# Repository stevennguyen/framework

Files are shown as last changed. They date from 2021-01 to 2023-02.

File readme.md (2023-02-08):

# 7c8 Framework
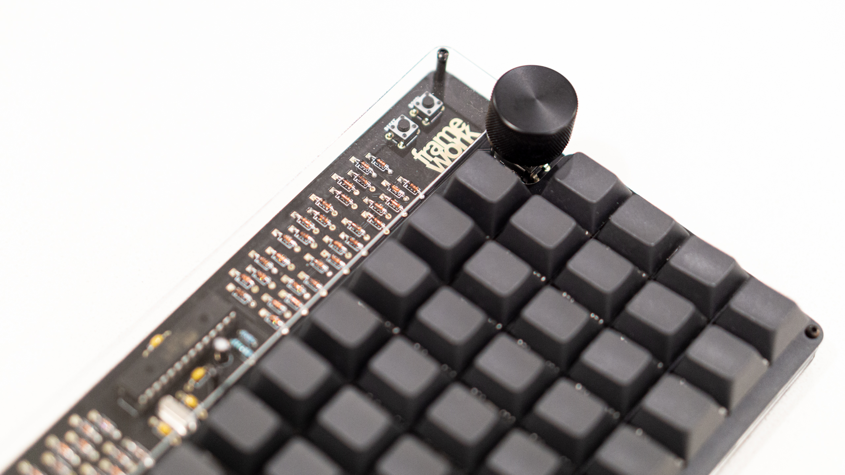
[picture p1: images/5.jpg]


Framework is a 5x12 ortholinear keyboard featuring:

* All through-hole components (except Kailh hotswap sockets)
* QMK firmware with VIA support
* Rotary encoder
* Hotswappable switches
* FR-4 and acrylic sandwich construction
* USB Type-C
* MIT (one 2u), grid (two 1u), and two 2u, bottom row configuration

## Info

### Discord

https://discord.gg/MpxnD9PygN

### License

Framework is licensed under [CC BY-NC-SA 4.0](https://creativecommons.org/licenses/by-nc-sa/4.0/). Please modify my design to make a keyboard that fits you!

### Revisions

**rev0** is an early prototype/proof of concept  
**rev1** is the current revision and should be used for fabrication or modification

### General

The ATmega328P does not come with a USB bootloader from factory. You will need to flash the chip with a bootloader through the ISP header first. You can find a pre-compiled .hex to flash at [USBaspLoader/bootloader.hex](USBaspLoader/bootloader.hex), or compile your own using the documentation found in the [USBaspLoader/](USBaspLoader/) folder. Everything has been preconfigured for use with the Framework.

[USBaspLoader](https://github.com/baerwolf/USBaspLoader) is a project maintained by [Stephan Baerwolf](https://github.com/baerwolf).

Fuse bytes should be:
* lfuse = 0xd7
* hfuse = 0xd0
* efuse = 0x04

After [setting up your QMK environment](https://docs.qmk.fm/#/newbs_getting_started), flash the Framework firmware:

```
make 7c8/framework:default:flash # default keymap
make 7c8/framework:via:flash     # via-compatible keymap
```

Alternatively, a precompiled .hex with bootloader and Framework QMK firmware with VIA support can be found at [firmware/bl_framework_via.hex](firmware/bl_framework_via.hex). Flashing/fusing with avrdude looks like this:

```
avrdude -c <programmer> -p atmega328p -U flash:w:bl_framework_via.hex:i -U lfuse:w:0xd7:m -U hfuse:w:0xd0:m -U efuse:w:0x04:m
```

### Layout

Framework supports MIT, grid, and 2x2u spacebar layouts. Refer to [framework.h](https://github.com/qmk/qmk_firmware/blob/master/keyboards/7c8/framework/framework.h). Layout options are also configurable in VIA.

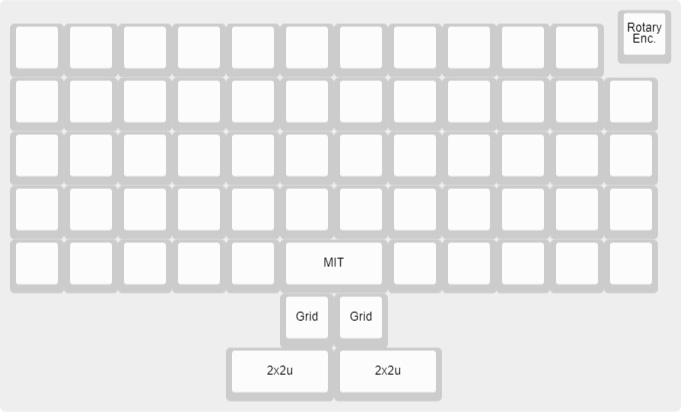
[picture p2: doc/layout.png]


### Physical construction

Please see [this separate note on physical construction](doc/physical_construction.md).

### Build guide

Please see the [build guide](doc/build_guide) for more information.

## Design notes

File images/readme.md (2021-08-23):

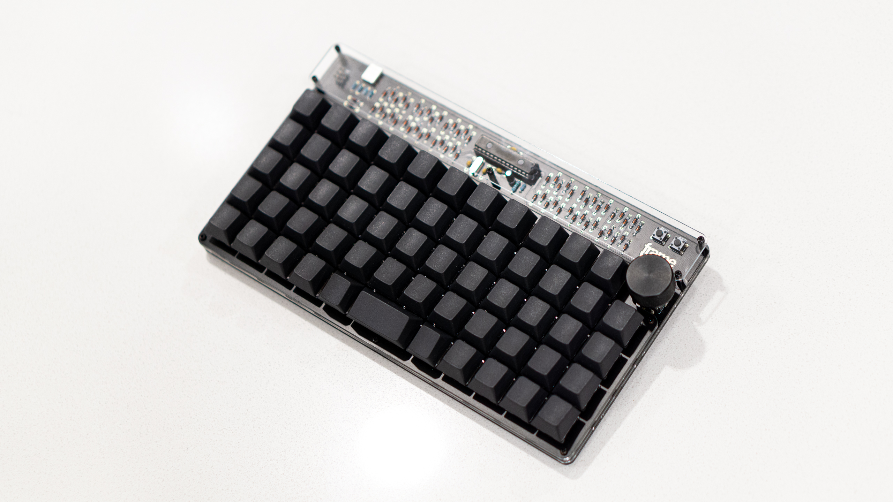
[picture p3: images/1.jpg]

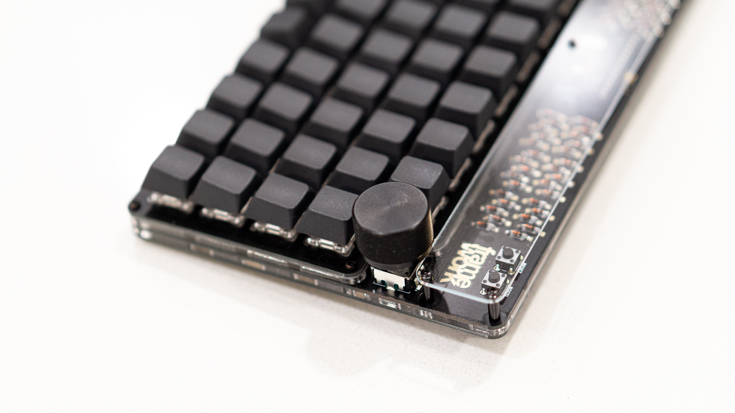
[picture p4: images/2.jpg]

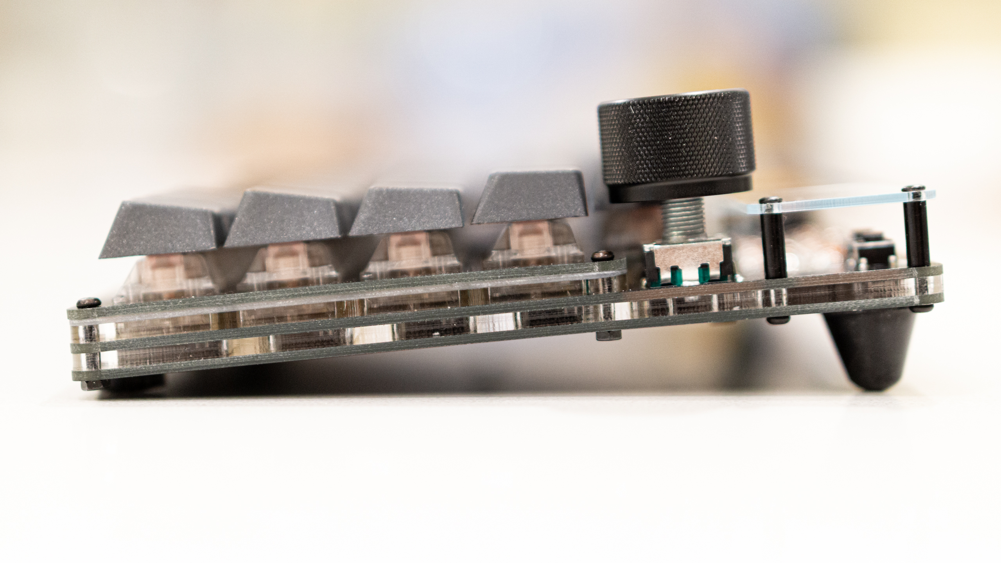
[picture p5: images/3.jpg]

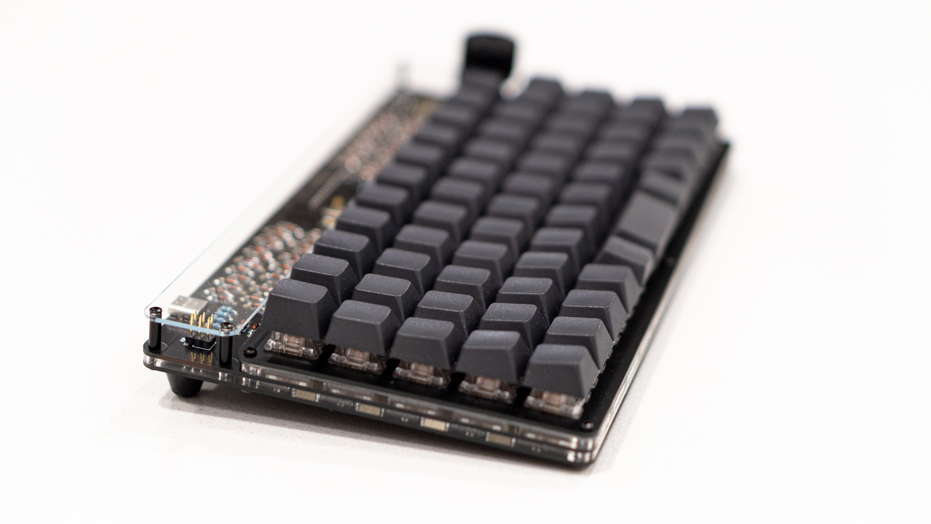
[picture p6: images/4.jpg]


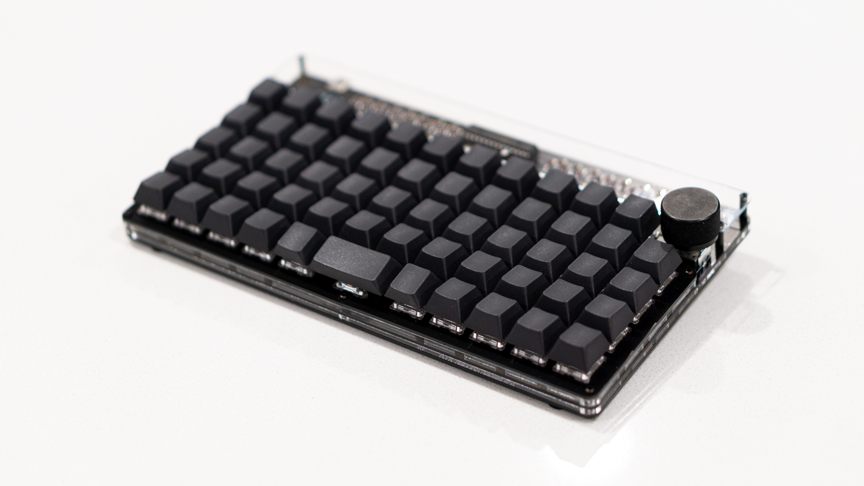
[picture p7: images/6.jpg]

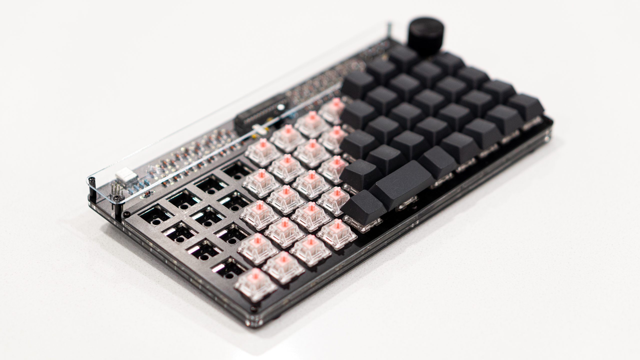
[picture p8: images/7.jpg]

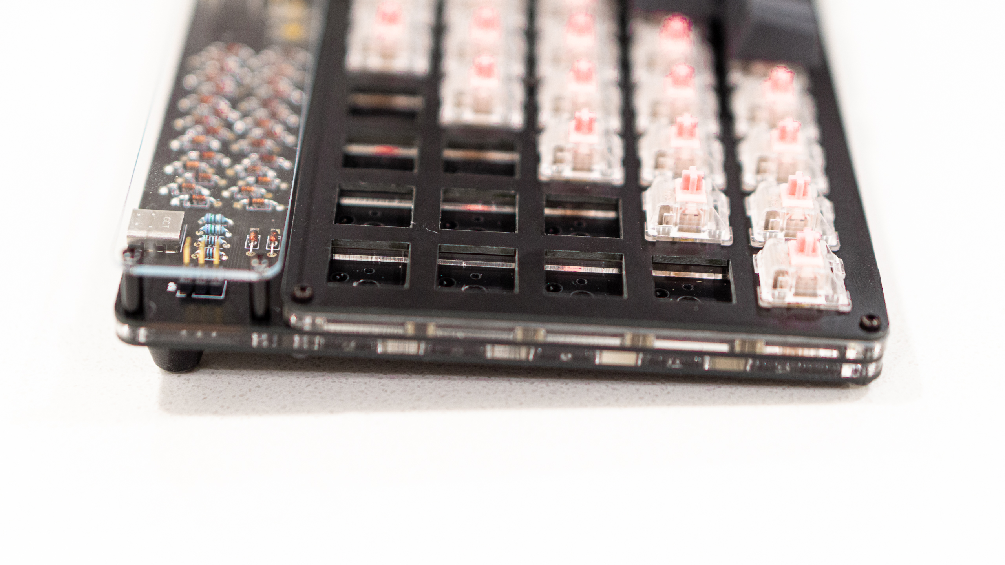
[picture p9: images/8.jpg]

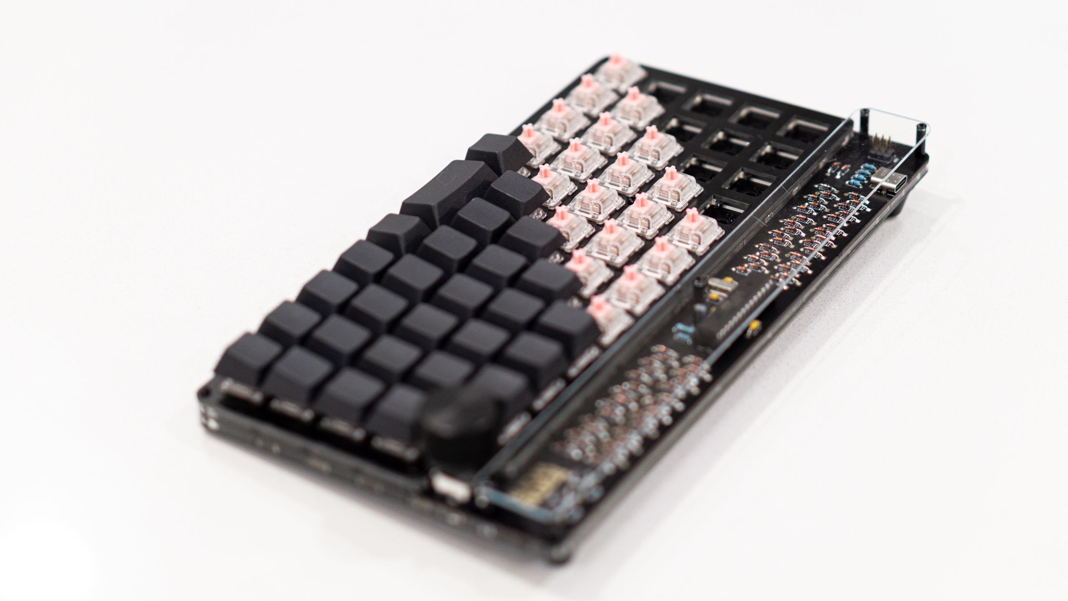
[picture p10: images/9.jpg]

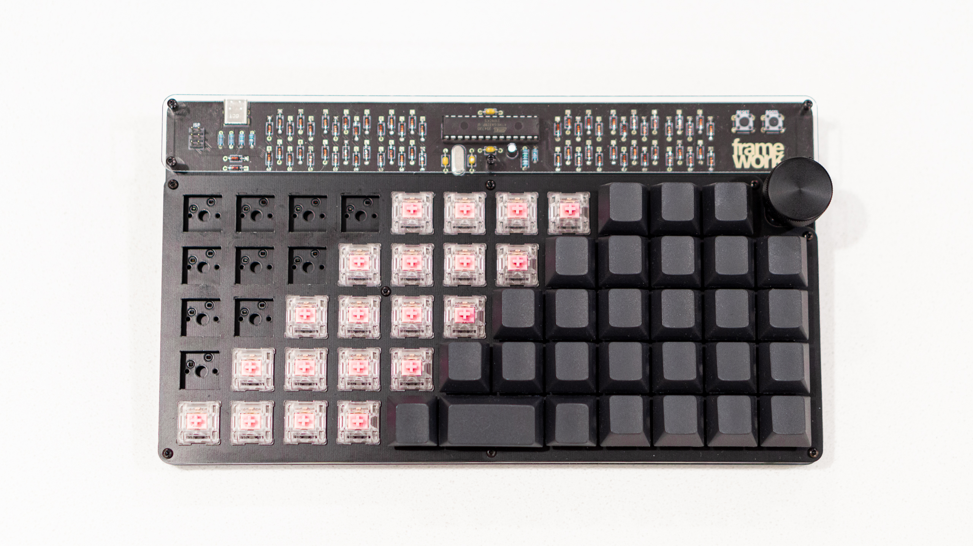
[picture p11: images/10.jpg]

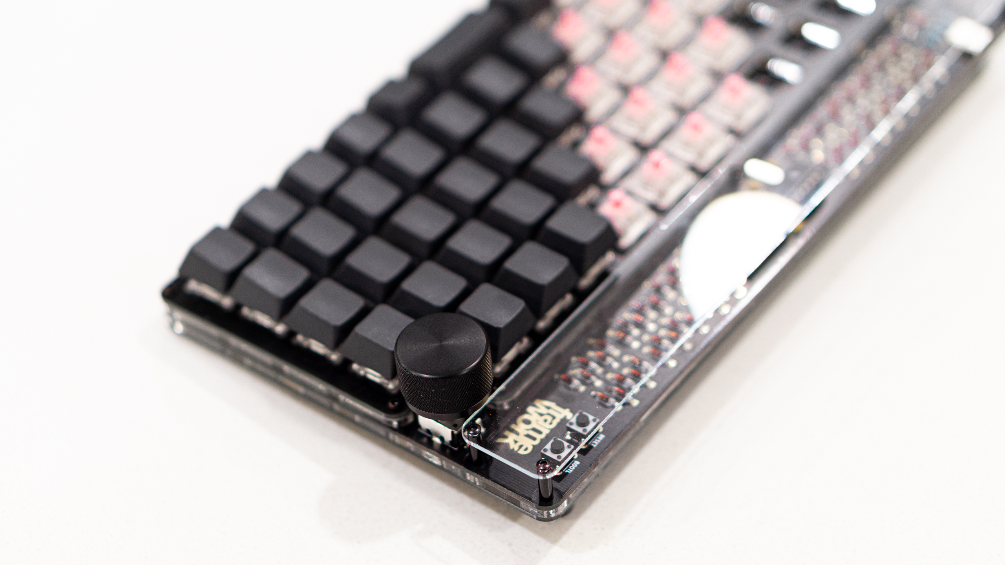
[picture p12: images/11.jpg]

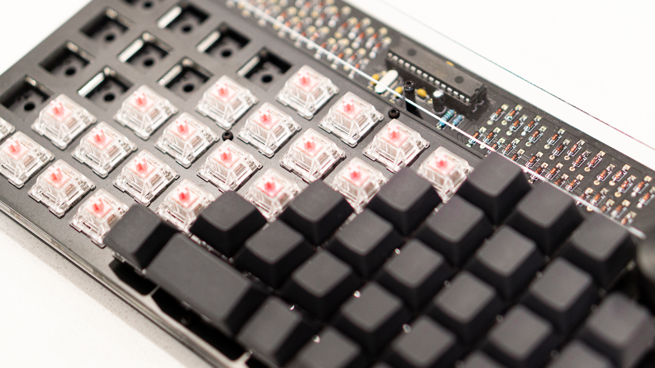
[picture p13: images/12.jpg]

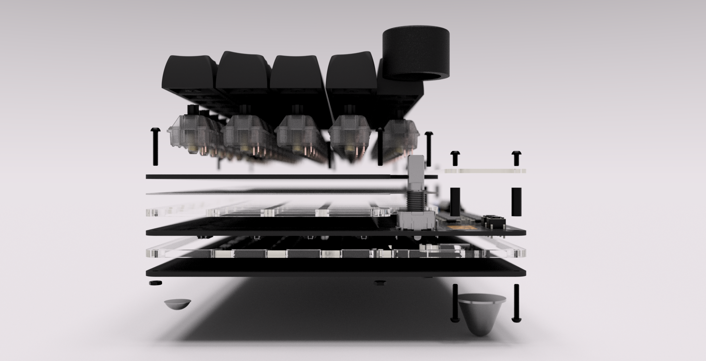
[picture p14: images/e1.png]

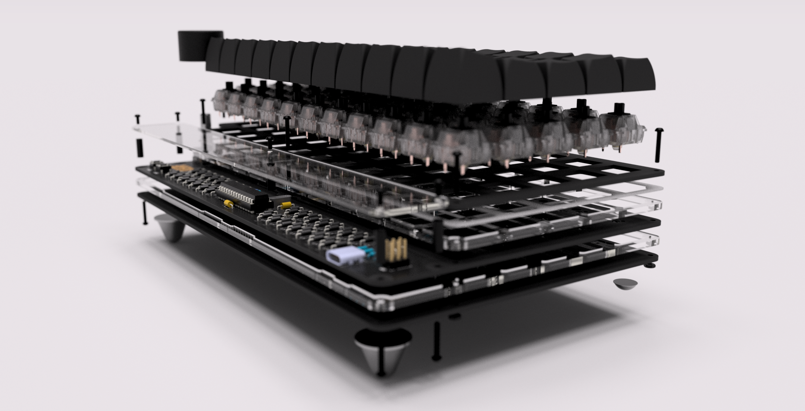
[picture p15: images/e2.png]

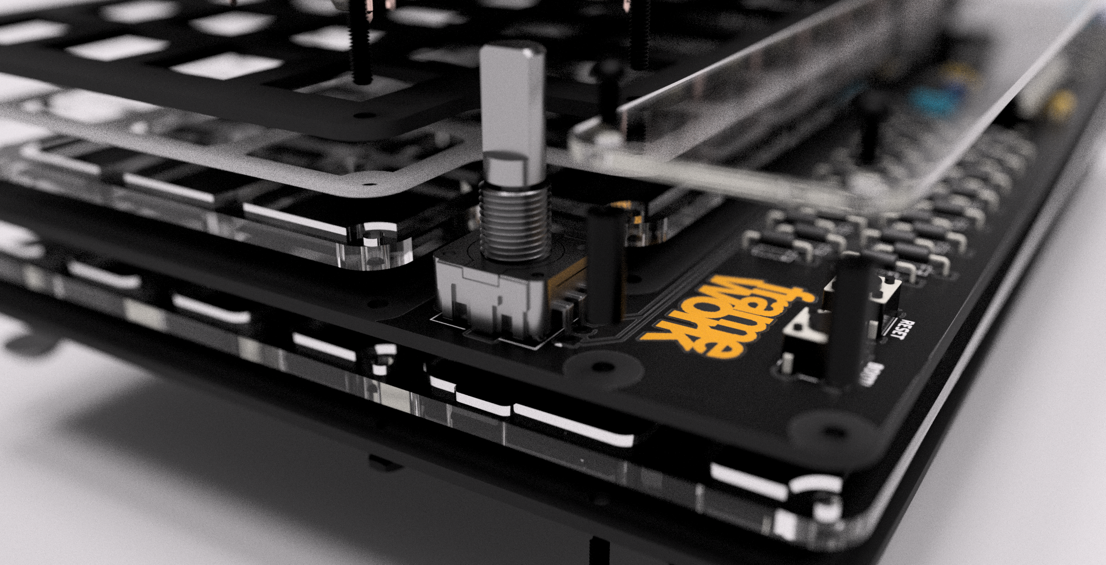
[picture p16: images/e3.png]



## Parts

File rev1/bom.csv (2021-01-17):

Id | Designator | Package | Quantity | Designation | Supplier and ref
1 | C1 | CP_Radial_D4.0mm_P1.50mm | 1 | 4u7
2 | G*** | framework_rev1 | 1 | LOGO
3 | G*** | 7c8stevennguyen | 1 | LOGO
4 | Y1 | Crystal_HC49-4H_Vertical | 1 | 16M
5 | U1 | DIP-28_W7.62mm | 1 | ATmega328P-PU
6 | SW65,SW64,SW62,SW61,SW60,SW59,SW58,SW57,SW56,SW55,SW54,SW53,SW52,SW51,SW50,SW49,SW48,SW47,SW46,SW45,SW44,SW43,SW42,SW41,SW40,SW39,SW38,SW37,SW36,SW35,SW34,SW33,SW32,SW31,SW30,SW29,SW28,SW27,SW26,SW25,SW24,SW23,SW22,SW21,SW20,SW19,SW18,SW17,SW16,SW15,SW14,SW13,SW12,SW11,SW10,SW9,SW8,SW7,SW6,SW5,SW4,SW3 | Kailh_socket_MX_no_fsilk | 62 | SW_Push_45deg
7 | SW63 | RotaryEncoder_Alps_EC11E-Switch_Vertical_H20mm | 1 | Rotary_Encoder_Switch
8 | SW2,SW1 | SW_PUSH_6mm_H4.3mm | 2 | SW_Push
9 | R6,R5 | R_Axial_DIN0204_L3.6mm_D1.6mm_P5.08mm_Horizontal | 2 | 5k1
10 | R4 | R_Axial_DIN0207_L6.3mm_D2.5mm_P7.62mm_Horizontal | 1 | 1k5
11 | R3,R2 | R_Axial_DIN0204_L3.6mm_D1.6mm_P5.08mm_Horizontal | 2 | 75
12 | R1 | R_Axial_DIN0204_L3.6mm_D1.6mm_P5.08mm_Horizontal | 1 | 10k
13 | J2 | USB_C_Receptacle_GCT_USB4085 | 1 | USB_C_Receptacle_USB2.0
14 | J1 | PinHeader_2x03_P2.54mm_Vertical | 1 | AVR-ISP-6
15 | D62,D61,D60,D59,D58,D57,D56,D55,D54,D53,D52,D51,D50,D49,D48,D47,D46,D45,D44,D43,D42,D41,D40,D39,D38,D37,D36,D35,D34,D33,D32,D31,D30,D29,D28,D27,D26,D25,D24,D23,D22,D21,D20,D19,D18,D17,D16,D15,D14,D13,D12,D11,D10,D9,D8,D7,D6,D5,D4,D3 | D_DO-35_SOD27_P7.62mm_Horizontal | 60 | D
16 | D2,D1 | D_DO-35_SOD27_P7.62mm_Horizontal | 2 | 3v6
17 | C5,C4 | C_Axial_L3.8mm_D2.6mm_P7.50mm_Horizontal | 2 | 22p
18 | C3,C2 | C_Axial_L3.8mm_D2.6mm_P7.50mm_Horizontal | 2 | 0u1
19 | G*** | framework | 1 | LOGO
20 | REF**,REF**,REF**,REF**,REF**,REF**,REF**,REF**,REF**,REF**,REF**,REF**,REF**,REF**,REF**,REF**,REF**,REF**,REF**,REF**,REF**,REF**,REF**,REF**,REF**,REF**,REF**,REF**,REF**,REF**,REF** | MountingHole_2.2mm_M2 | 31 | MountingHole_2.2mm_M2
21 | REF**,REF**,REF** | Stabilizer_MX_2u | 3 | Stabilizer_MX_2u
22 | G*** | keyswitch | 1 | LOGO
23 | mouse-bite-2mm-slot,mouse-bite-2mm-slot,mouse-bite-2mm-slot,mouse-bite-2mm-slot,mouse-bite-2mm-slot,mouse-bite-2mm-slot,mouse-bite-2mm-slot,mouse-bite-2mm-slot,mouse-bite-2mm-slot,mouse-bite-2mm-slot | mouse-bite-2mm-slot | 10 | VAL**

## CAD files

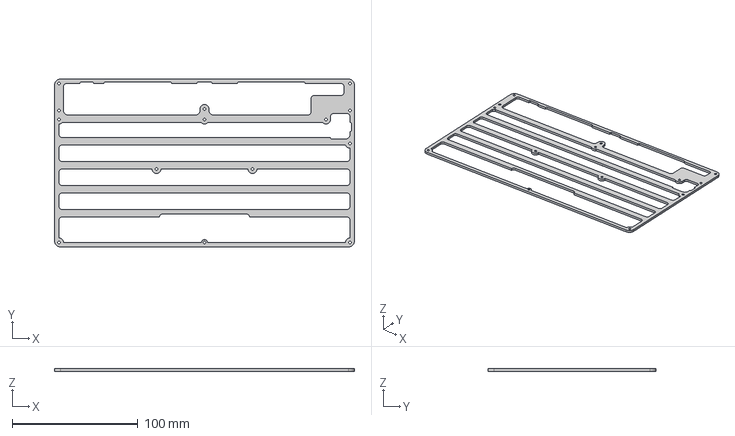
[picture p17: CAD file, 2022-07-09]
rev1/3d_layers/bottom.step
238.1 x 133.4 x 2.00 mm

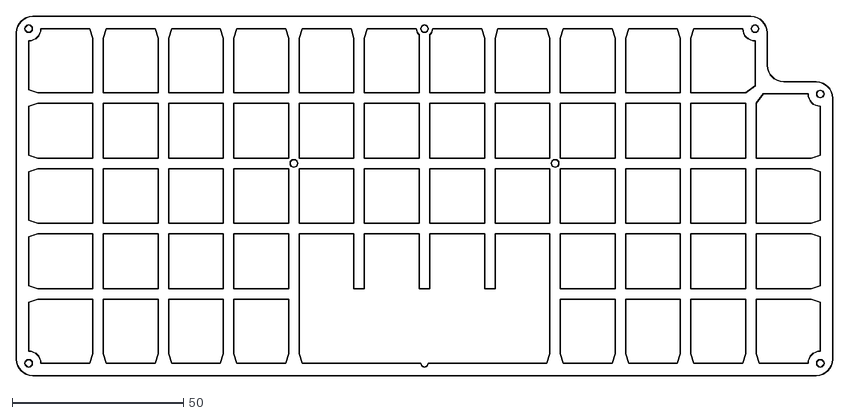
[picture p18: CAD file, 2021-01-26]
rev1/acrylic/dxf/framework-acrylic-grid-Edge_Cuts.dxf
238.1 x 104.8

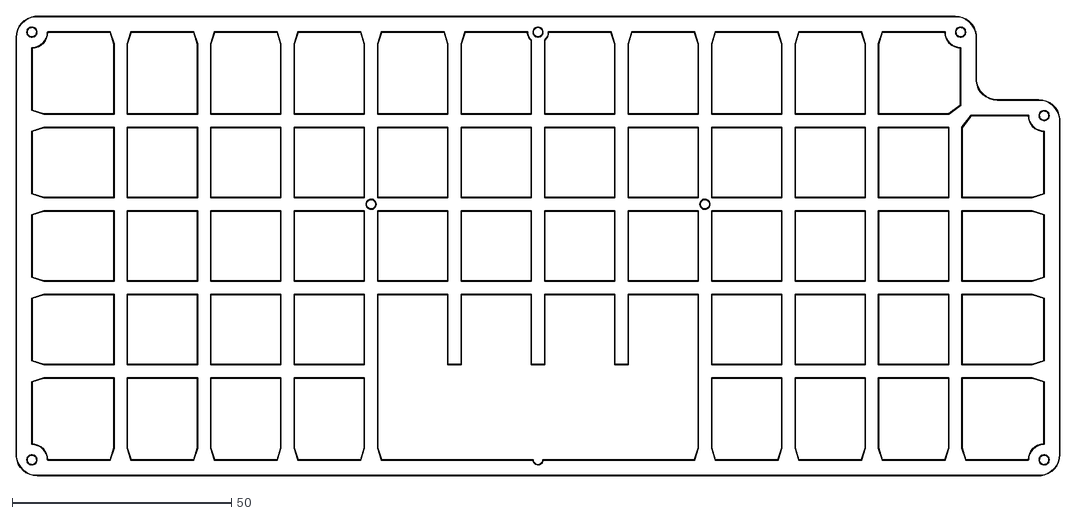
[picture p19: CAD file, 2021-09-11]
rev1/dxf_layers/dxf/framework-acrylic-upper.dxf
238.2 x 104.8

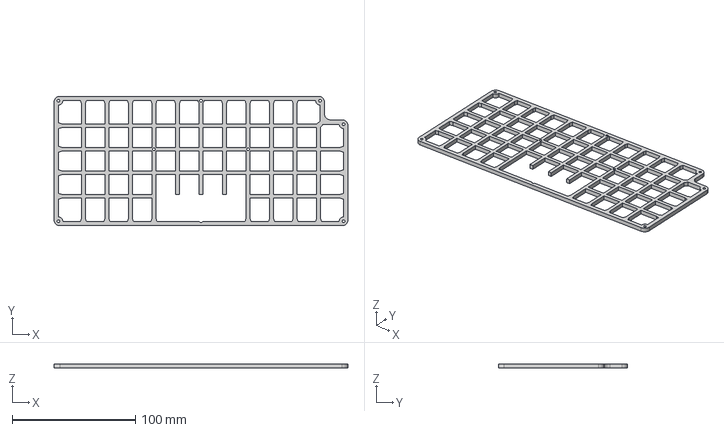
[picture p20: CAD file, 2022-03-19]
rev1/3d_layers/top.step
238.1 x 104.8 x 3.50 mm

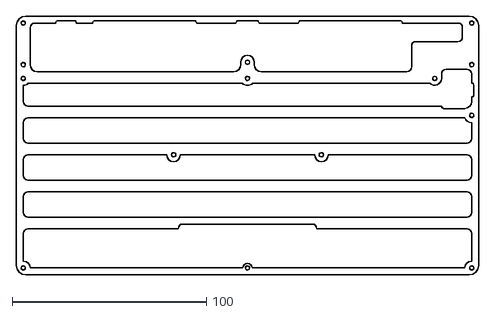
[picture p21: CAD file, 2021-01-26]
rev1/dxf_layers/dxf/framework-acrylic-lower.dxf
238.1 x 133.3

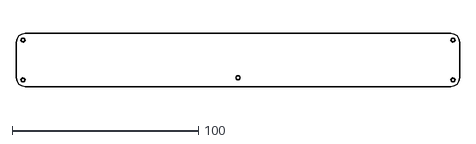
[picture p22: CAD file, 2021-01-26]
rev1/dxf_layers/dxf/framework-acrylic-shield.dxf
238.1 x 28.6

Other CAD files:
rev1/3d_layers/bottom.stl
rev1/3d_layers/top.stl

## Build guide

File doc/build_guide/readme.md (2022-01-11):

# Framework build guide

## Kit contents
### Non-electronic components
Component                               | Image                                | Note
--------------------------------------- | ------------------------------------ | ----
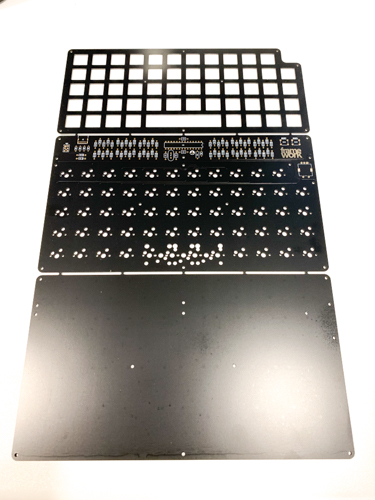
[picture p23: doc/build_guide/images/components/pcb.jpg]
1x Switch plate/PCB/back plate assembly |        |
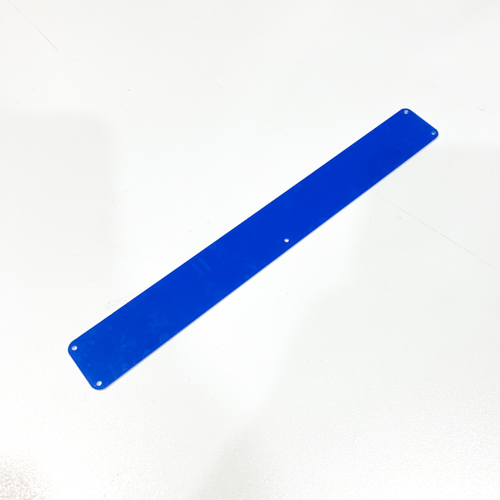
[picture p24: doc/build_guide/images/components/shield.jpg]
1x Acrylic component shield             |     | 
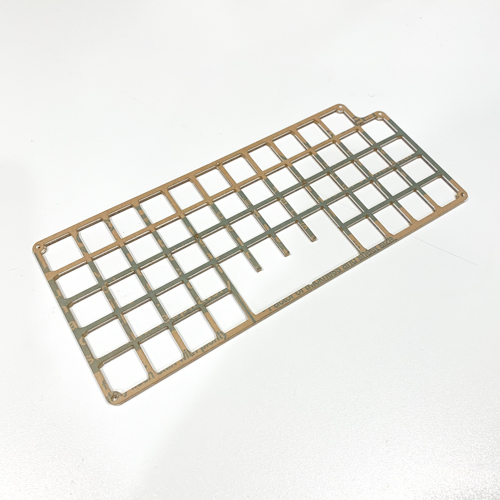
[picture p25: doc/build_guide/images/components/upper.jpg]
1x Acrylic upper                        |      | Peel the protective paper backing from the acrylic if present. Not all acrylic pieces across kits will have this backing.
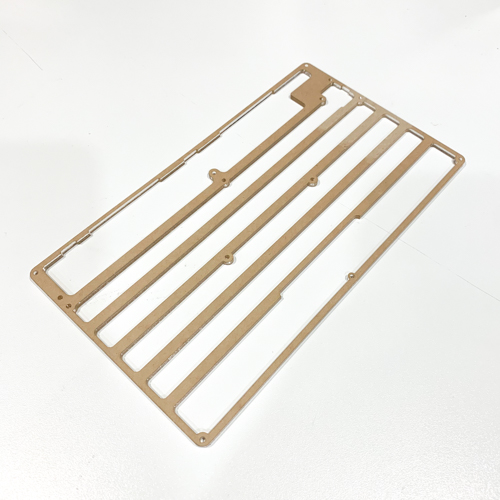
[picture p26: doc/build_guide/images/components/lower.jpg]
1x Acrylic lower                        |      | As above. ^
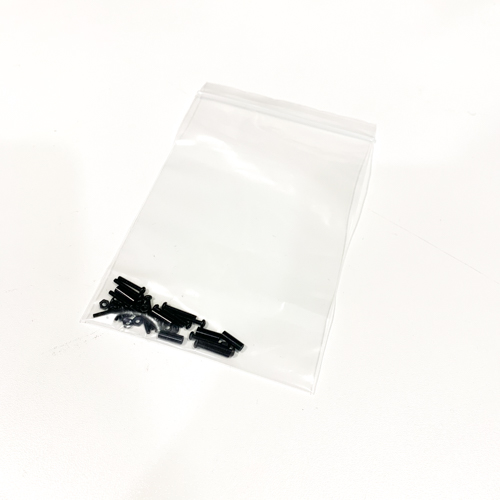
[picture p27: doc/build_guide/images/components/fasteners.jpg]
1x Fastener set                         |  |
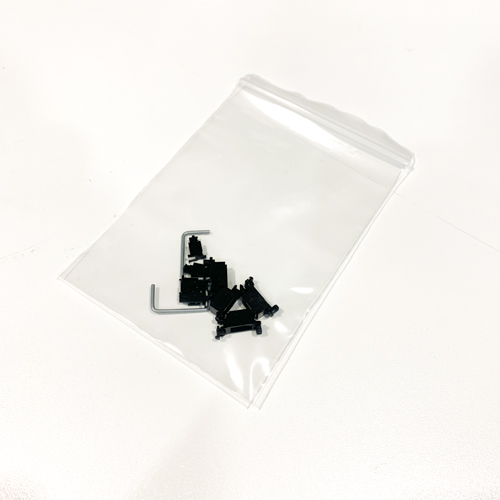
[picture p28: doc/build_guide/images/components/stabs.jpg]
2x 2u Cherry stabilizers                |      |
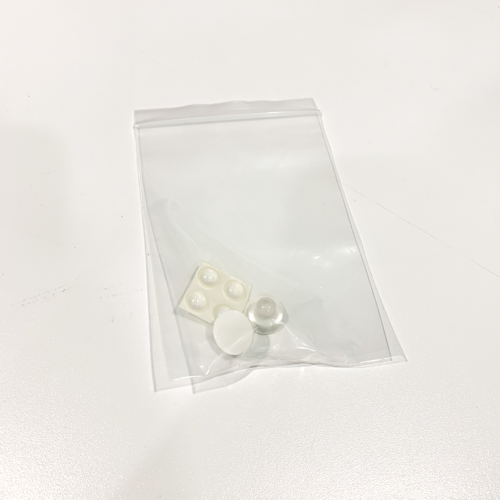
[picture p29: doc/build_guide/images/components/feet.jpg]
1x Rubber feet                          |       | Rubber feet included for slanted or flat orientation.

### Electronic components
Component                     | Image                                 | Note
----------------------------- | ------------------------------------- | ----
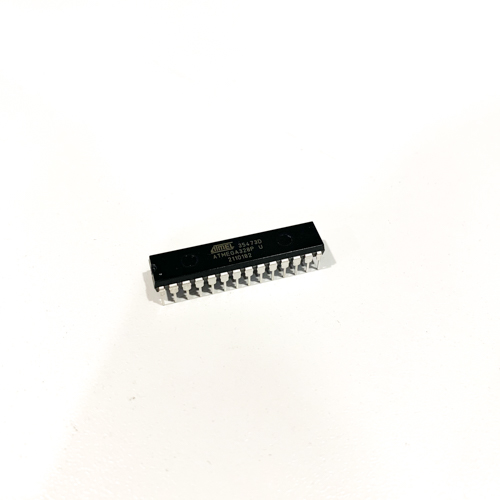
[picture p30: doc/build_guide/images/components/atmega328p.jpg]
1x ATmega328P microcontroller |  | 
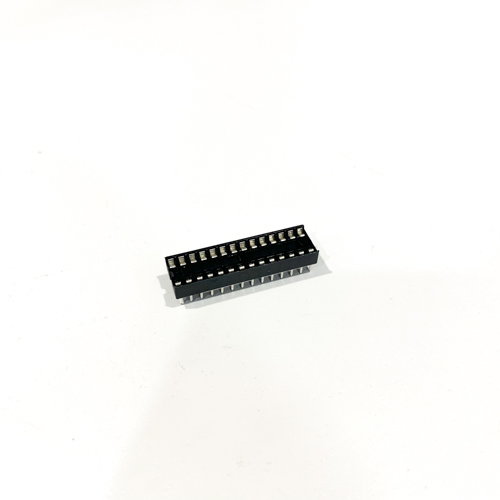
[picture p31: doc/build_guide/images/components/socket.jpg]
1x 28-pin DIP socket          |      | 
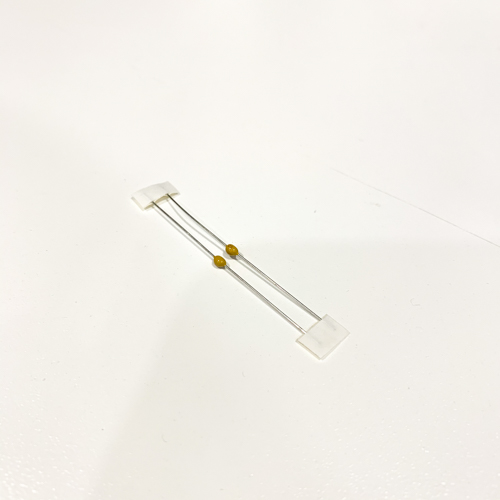
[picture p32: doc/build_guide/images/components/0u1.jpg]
2x 0.1 uF capacitors          |         | 
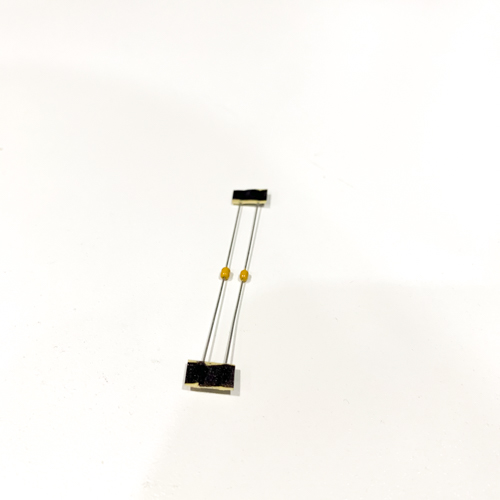
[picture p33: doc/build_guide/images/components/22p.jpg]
2x 22 pF capacitors           |         | These capacitors have a black marking on the reel tape for easy identification.
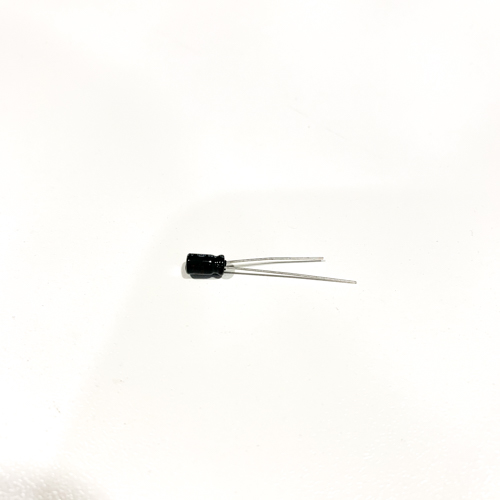
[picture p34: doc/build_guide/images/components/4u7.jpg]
1x 4.7 uF capacitor           |         | 
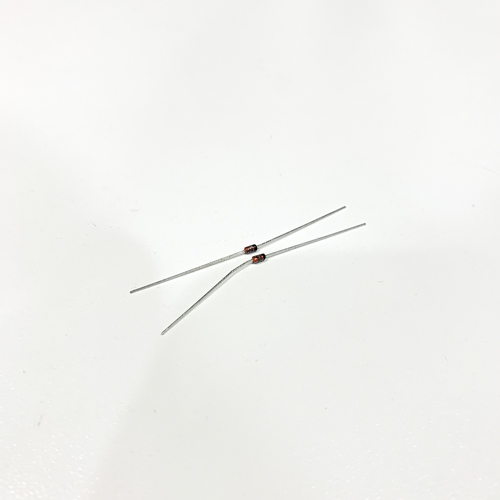
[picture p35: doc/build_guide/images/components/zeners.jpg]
2x Zener diodes               |      | 
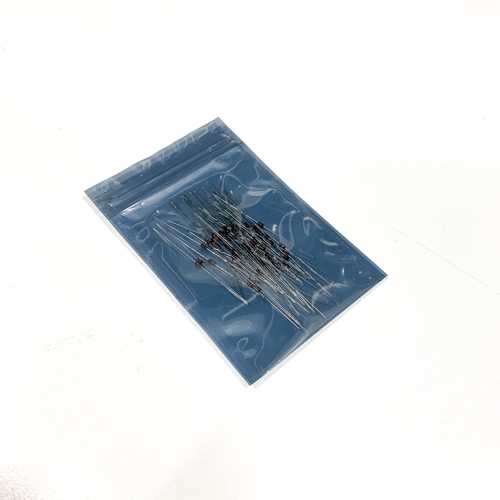
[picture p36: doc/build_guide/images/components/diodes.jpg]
60x Diodes                    |      | These are easy to confuse with the 2 zener diodes in the other component bag, so please keep these separate.
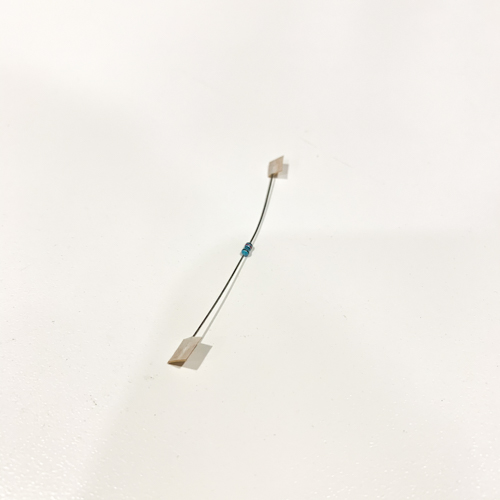
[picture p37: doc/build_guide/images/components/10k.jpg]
1x 10k ohm resistor           |         | Brown Black Black Red Brown
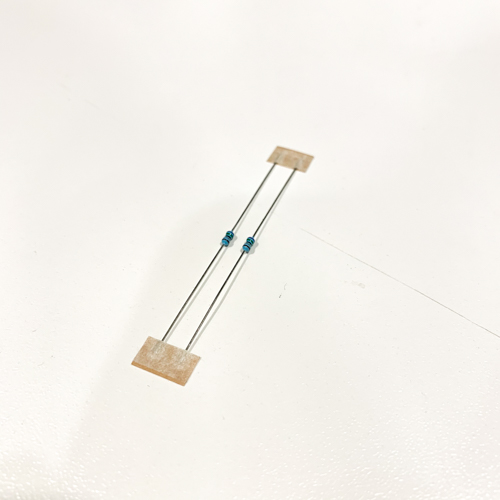
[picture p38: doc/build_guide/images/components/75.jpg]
2x 75 ohm resistors           |          | Purple Green Black Gold Brown
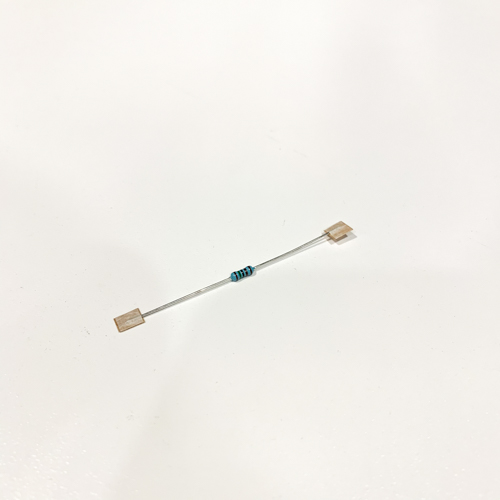
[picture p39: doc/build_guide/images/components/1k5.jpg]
1x 1.5k ohm resistor          |         | Brown Green Black Brown Brown
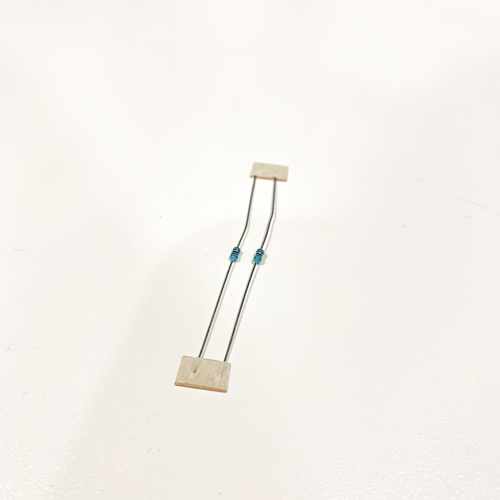
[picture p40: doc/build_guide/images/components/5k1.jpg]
2x 5.1k ohm resistors         |         | Green Brown Black Brown Brown
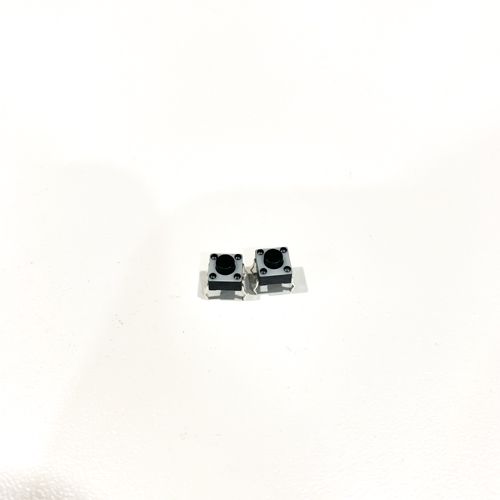
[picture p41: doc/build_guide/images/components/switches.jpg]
2x Tactile switches           |    | 
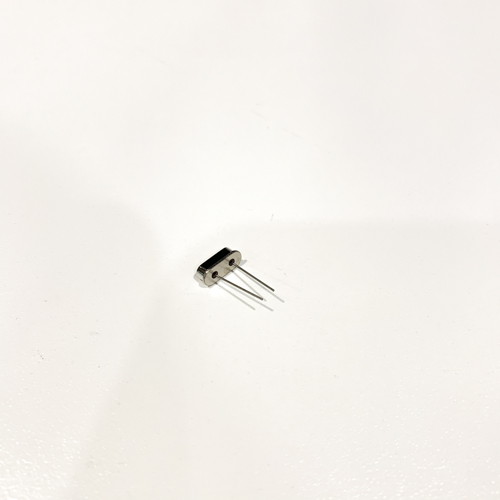
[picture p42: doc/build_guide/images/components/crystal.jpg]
1x 16 MHz crystal             |     | 
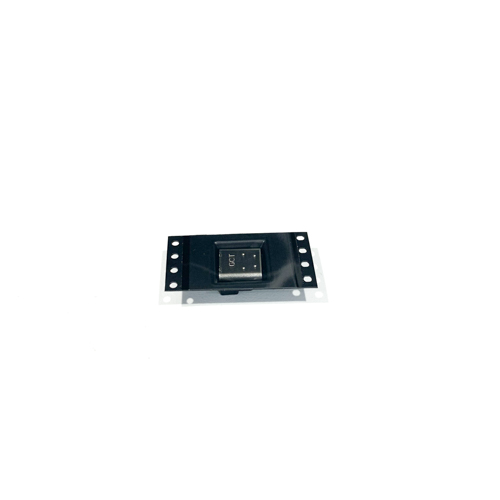
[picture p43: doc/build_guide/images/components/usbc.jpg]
1x USB C connector            |        | 
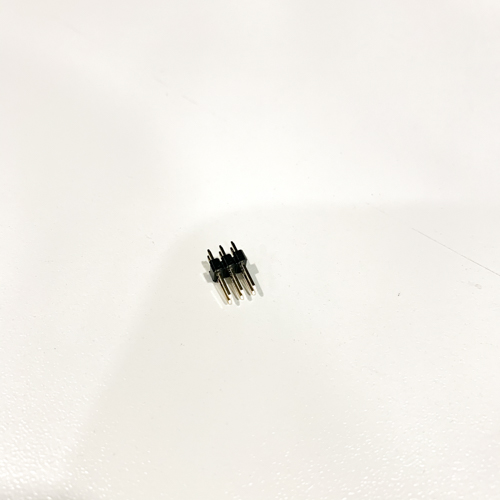
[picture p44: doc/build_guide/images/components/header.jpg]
1x 6-pin header               |      | 
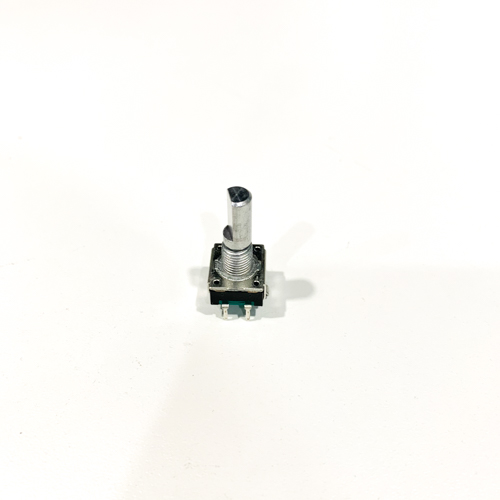
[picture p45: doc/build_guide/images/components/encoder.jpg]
1x Rotary encoder             |     | 
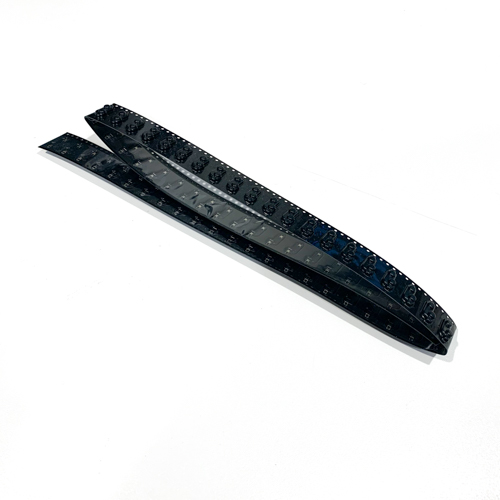
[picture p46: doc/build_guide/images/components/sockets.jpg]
62x Kailh hot-swap sockets    |     | 

### Optional components (depending on kit variant)
Component                            | Image                             | Note
------------------------------------ | --------------------------------- | ----
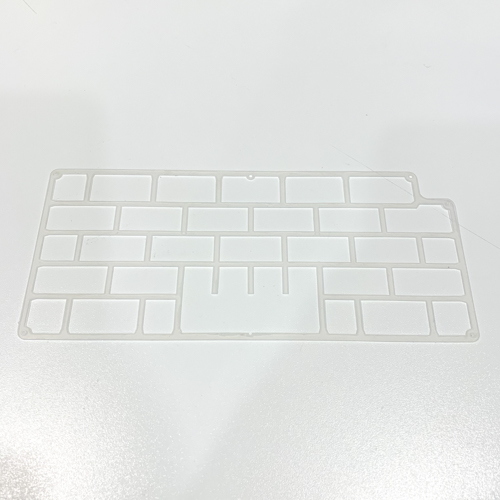
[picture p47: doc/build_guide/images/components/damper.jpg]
Silicone plate damper (1.0 mm shown) |  | Your damper may look different
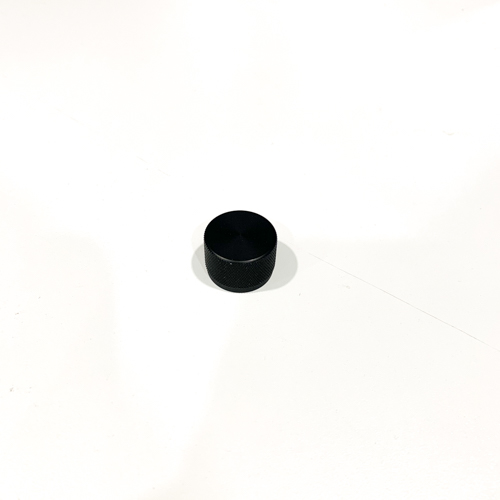
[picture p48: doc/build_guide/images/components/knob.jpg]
Rotary encoder knob                  |    |

## Additional items to complete the keyboard
- Key switches (MX footprint)
- Key caps
- Rotary encoder knob

## Required materials and tools
- Soldering iron
- Solder flux
- Solder
- Isopropyl alcohol
- Wire cutters
- Tape (to hold the components to the board while you solder)
- Pliers (to remove panelization tabs)
- Sandpaper or a nail file (to sand down panelization mouse bites)
- 1.3 mm hex key (for fasteners)
- 4 mm nut driver or wrench (for fasteners)
- 1/16 inch or 1.5 mm hex key (for knob set screw)

## Table of contents
1. [Depanelize plates and PCB](#step1)
2. [Solder R5, R6 (5.1k ohm resistors)](#step2)
3. [Solder R2, R3 (75 ohm resistors)](#step3)
4. [Solder D1, D2 (zener diodes)](#step4)
5. [Solder D3 to D62 (diodes)](#step5)
6. [Solder C2, C3 (0.1 uF capacitors)](#step6)
7. [Solder C4, C5 (22 pF capacitors)](#step7)
8. [Solder R1 (10k ohm resistor)](#step8)
9. [Solder R4 (1.5k ohm resistor)](#step9)
10. [Solder Y1 (crystal)](#step10)
11. [Solder U1 (DIP socket)](#step11)
12. [Solder C1 (4.7 uF capacitor)](#step12)
13. [Solder SW1, SW2 (tactile switches)](#step13)
14. [Solder J2 (USB C connector)](#step14)
15. [Solder J1 (6-pin ISP header)](#step15)
16. [Solder rotary encoder](#step16)
17. [Solder Kailh hot-swap sockets](#step17)
18. [Clean your PCB with alcohol](#step18)
19. [Assemble and install stabilizers if desired](#step19)
20. [Assemble keyboard](#step20)
21. [Install switches and keycaps](#step21)

## Assembly

Note: Please take care to make sure pins are straight (especially on the microcontroller and USB C connector) and that components are soldered flush and evenly on the board.

### Step 1: Depanelize plates and PCB 
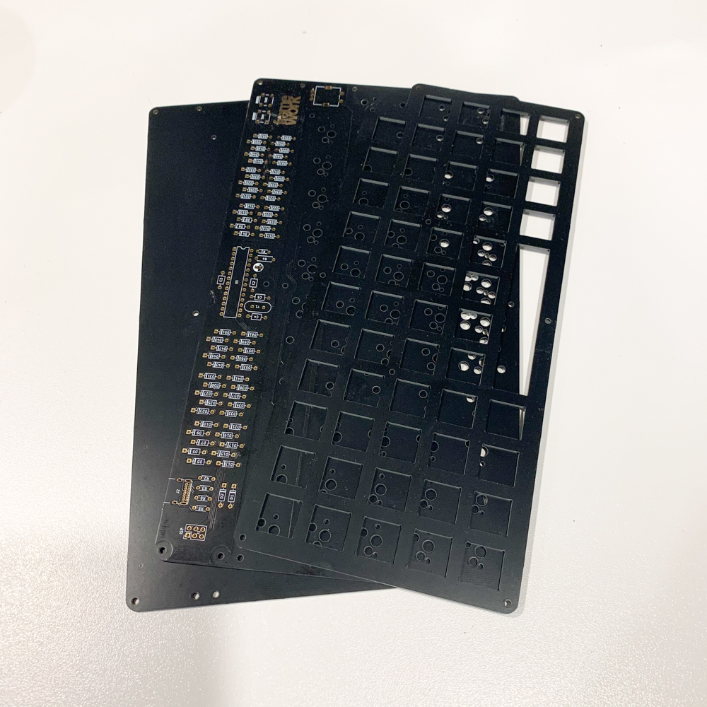
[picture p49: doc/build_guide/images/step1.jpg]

Snap off the individual panels by hand. You'll want to use pliers to break off the little tabs, then sand/file them flush with the panel/PCB.

### Step 2: Solder R5, R6 (5.1k ohm resistors) 
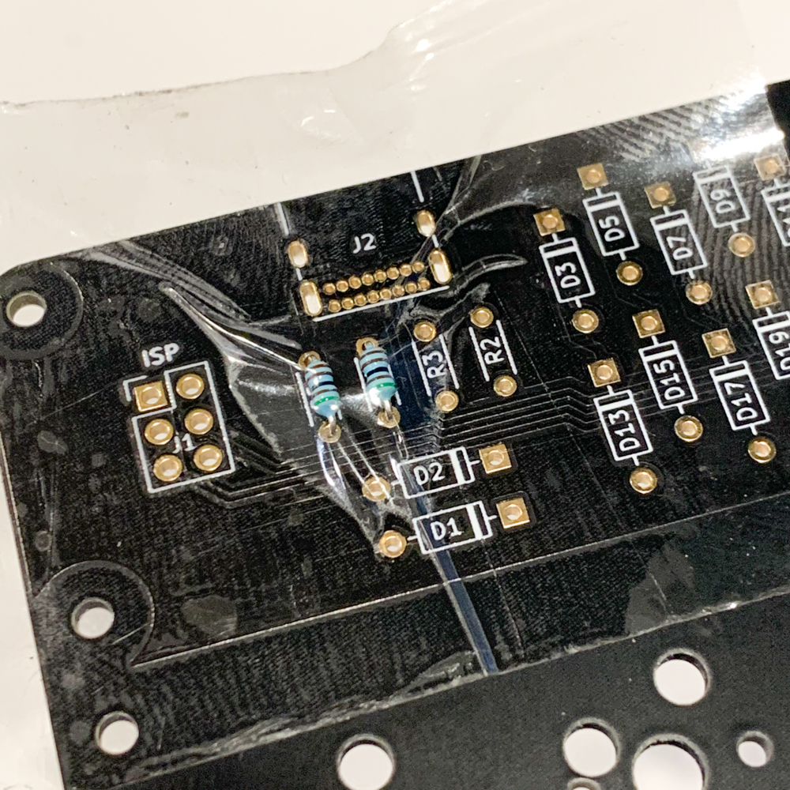
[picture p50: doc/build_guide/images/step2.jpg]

I like to use tape to secure the components to the board to make sure they stay flat on the board as I'm soldering. You could also bend the legs to keep them in place as well.

**R5 and R6 (5.1k ohm, Green Brown Black Brown Brown)** have no polarity (can be installed in any direction, as with all other resistors).

After you solder components, snip off the excess lead with wire cutters (unless specific otherwise).

### Step 3: Solder R2, R3 (75 ohm resistors) 
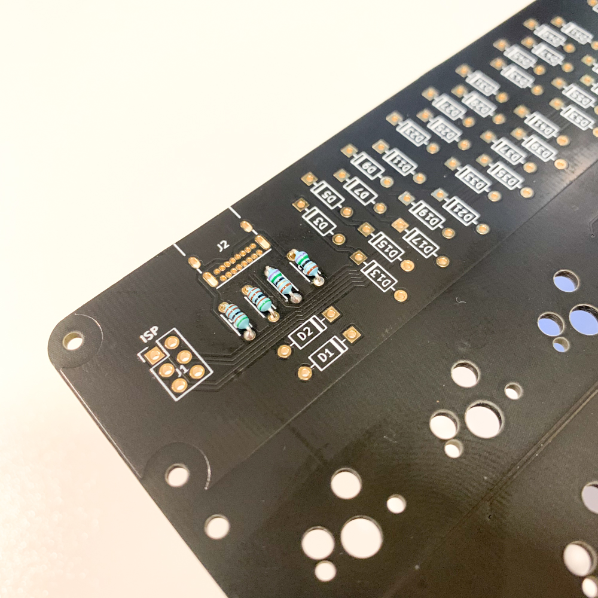
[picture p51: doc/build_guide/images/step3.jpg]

Install and solder **R2 and R3 (75 ohm, Purple Green Black Gold Brown)** the same way as the other resistors.

### Step 4: Solder D1, D2 (zener diodes) 
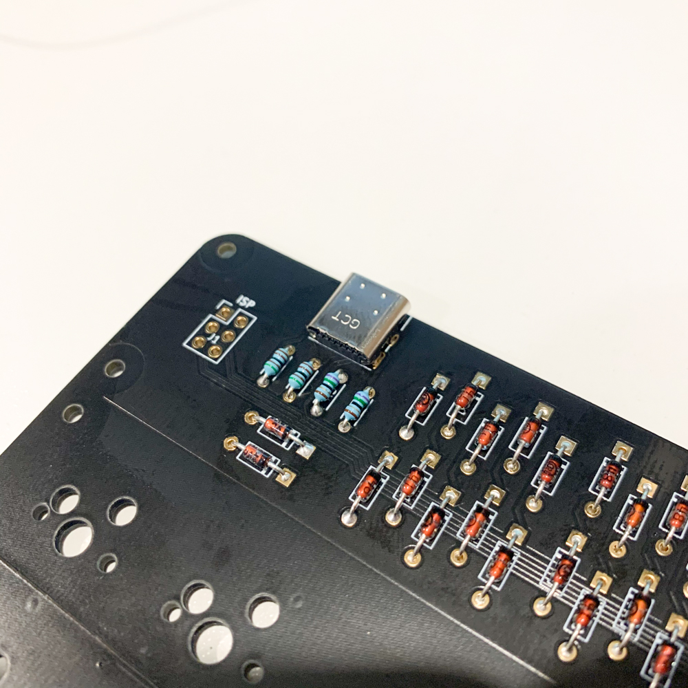
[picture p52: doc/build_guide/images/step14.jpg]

Install and solder **D1 and D2** zener diodes. These components are **polar** and the **black band on the zener diode should match the band on the silkscreen footprint**.

(image to show orientation is from step 14, my fault for neglecting to photograph this step)

### Step 5: Solder D3 to D62 (diodes) 
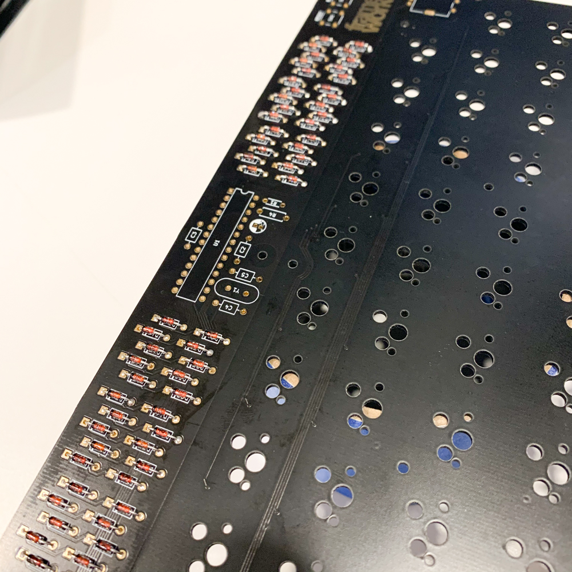
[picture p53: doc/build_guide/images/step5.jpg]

Install and solder the switch matrix diodes **D3 to D54**. You can install these in banks of five (or all at once if you desire). These components are **polar** and the **black band on the diodes should match the band on the silkscreen footprint**.

### Step 6: Solder C2, C3 (0.1 uF capacitors) 
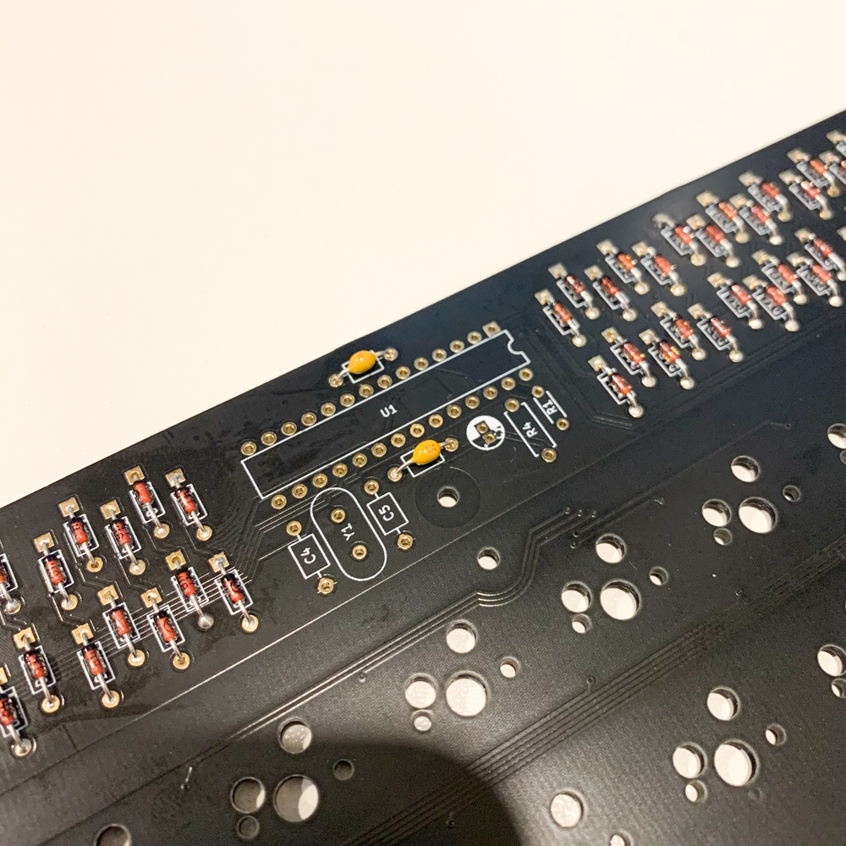
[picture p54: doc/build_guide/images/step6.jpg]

Of the two sets of ceramic capacitors, these are the ones **WITHOUT** the black marking on the reel tape. These can be installed and soldered in any direction.

### Step 7: Solder C4, C5 (22 pF capacitors) 
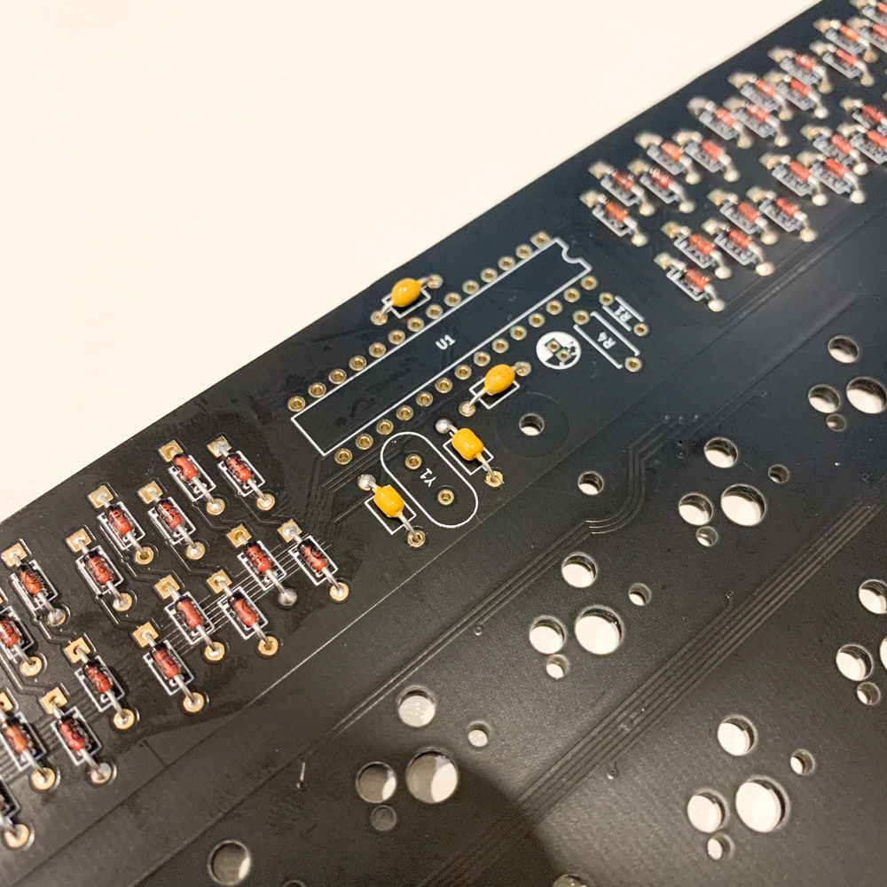
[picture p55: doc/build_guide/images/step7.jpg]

Of the two sets of ceramic capacitors, these are the ones **WITH** the black marking on the reel tape. These can be installed and soldered in any direction.

### Step 8: Solder R1 (10k ohm resistor) 
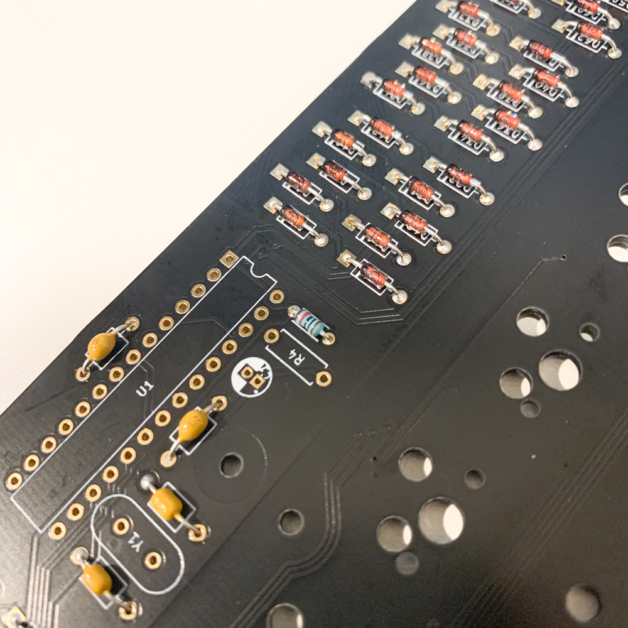
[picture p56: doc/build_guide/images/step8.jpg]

**R1 (10k ohm, Brown Black Black Red Brown)** can be installed and soldered in any direction.

### Step 9: Solder R4 (1.5k ohm resistor) 
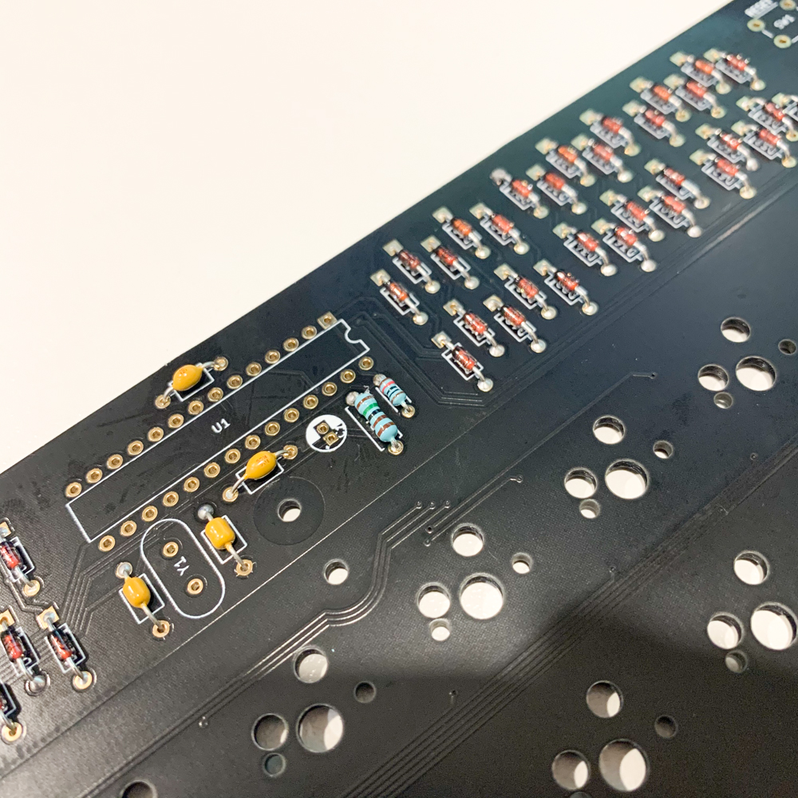
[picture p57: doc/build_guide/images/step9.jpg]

**R4 (1.5k ohm, Brown Green Black Brown Brown)** can be installed and soldered in any direction.

### Step 10: Solder Y1 (crystal) 
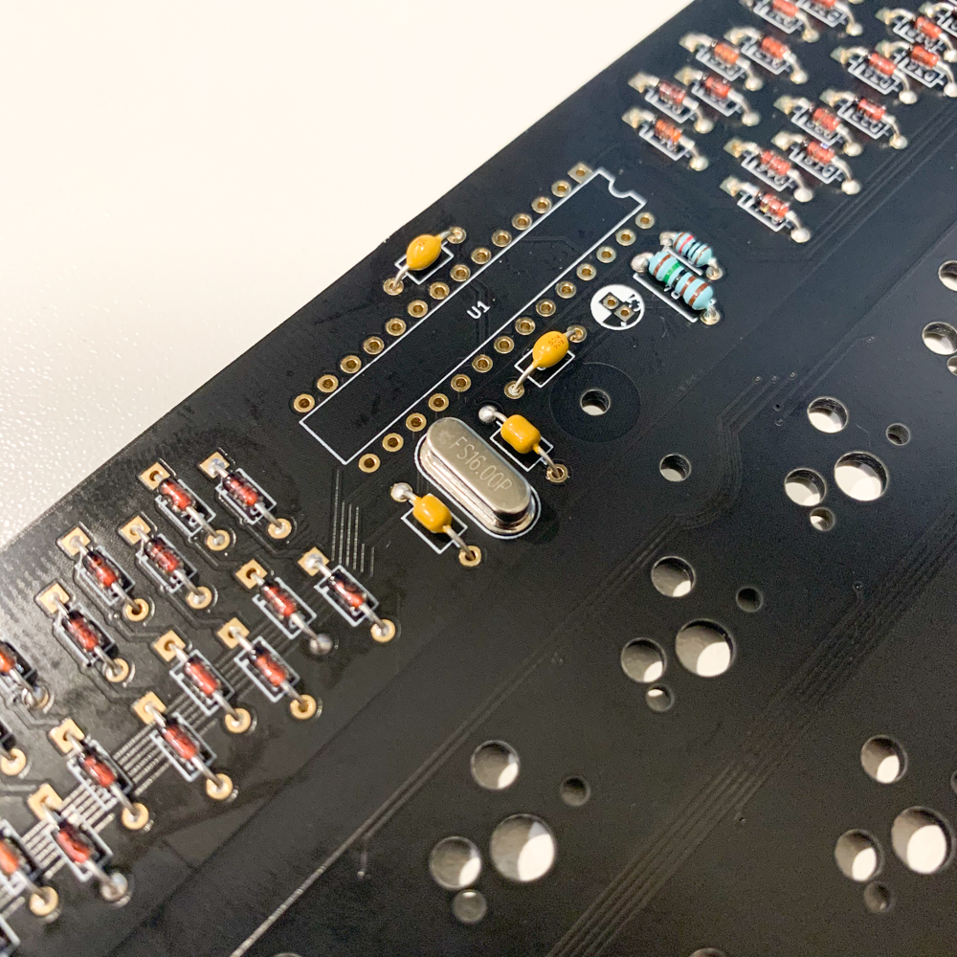
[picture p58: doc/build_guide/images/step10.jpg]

**Y1 can be installed and soldered in any direction.**

### Step 11: Solder U1 (DIP socket) 
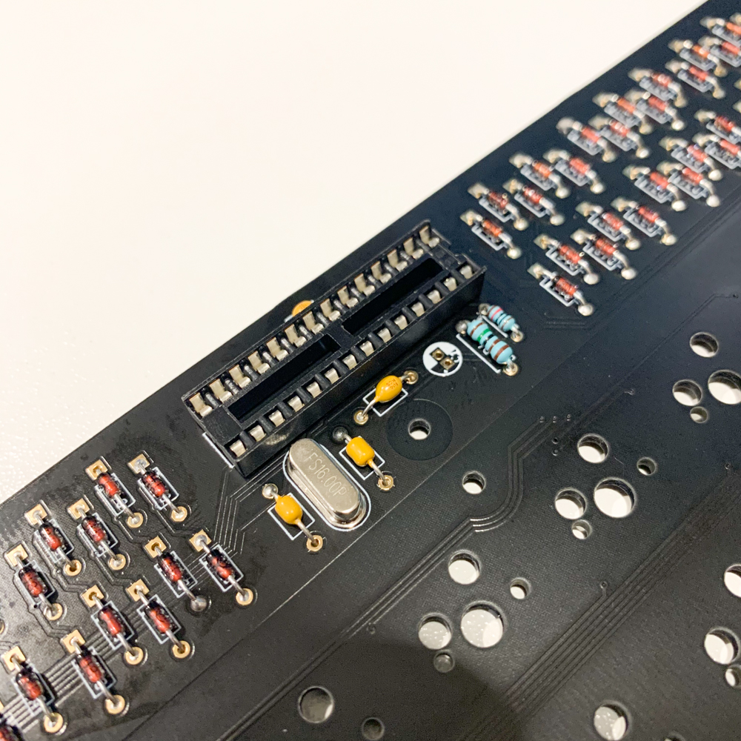
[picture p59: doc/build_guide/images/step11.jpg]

Take care to align the notch in the DIP socket with the notch on the silkscreen footprint. It's not necessary to trim the leads after soldering. Insert the ATmega328P IC (or do it later), making sure the notch on the chip matches the notch on the socket and silkscreen footprint.

### Step 12: Solder C1 (4.7 uF capacitor) 
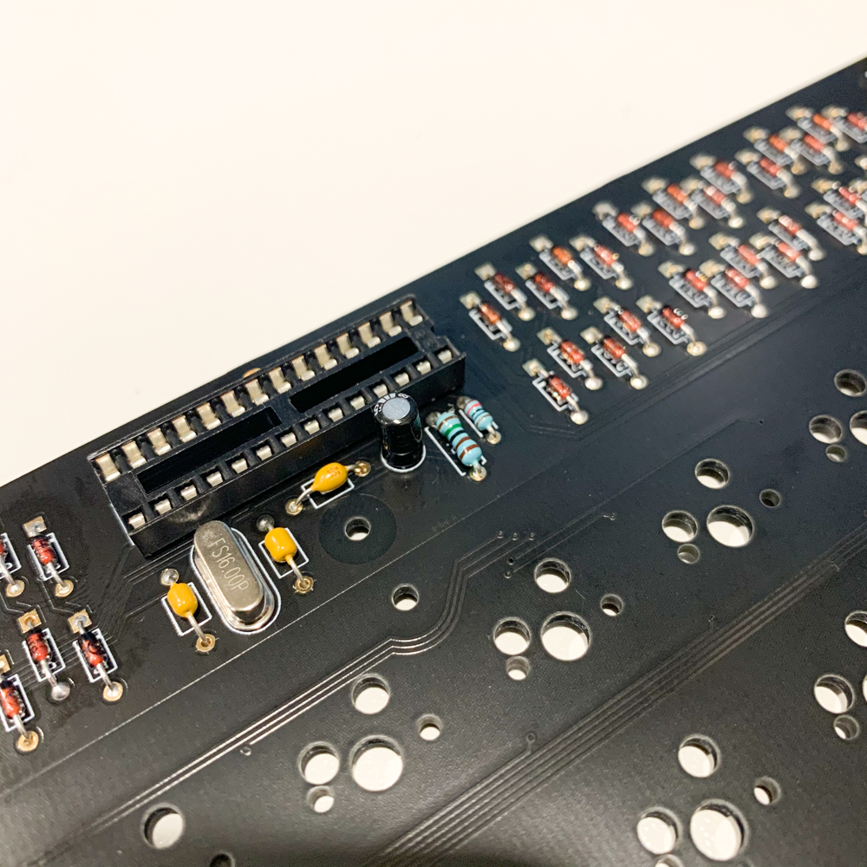
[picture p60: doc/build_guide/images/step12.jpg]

**C1 is polar. Align the white band of the capacitor with the filled hemisphere on the silkscreen footprint.**

### Step 13: Solder SW1, SW2 (tactile switches) 
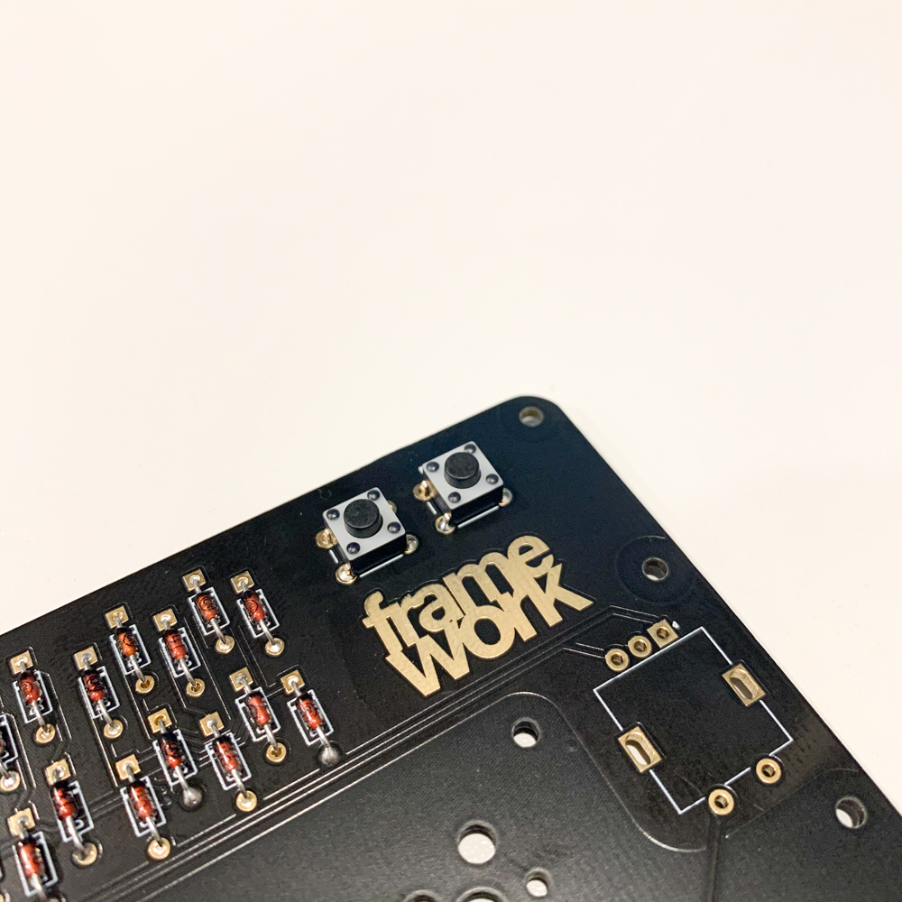
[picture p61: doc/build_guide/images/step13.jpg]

It's not necessary to trim the leads after soldering.

### Step 14: Solder J2 (USB C connector) 

**Warning: this is very tricky to solder due to the fine pitch! Please take care in soldering this connector.**

Please refer to this [video](https://youtu.be/fXujFUUJmBg?t=171) as an example.

Solder one mounting tab first and ensure that the connector is flat on the board and aligned straight. After its orientation looks correct, solder the other three mounting legs.

Use a generous amount of flux on the pins. Apply a little bit of solder to your soldering iron and "dab" the solder onto each individual pin. You can also drag your tinned soldering iron tip across the pins. Carefully inspect the solder joints to make sure there are no solder bridges. If there are any solder bridges, go back and reflow the solder joints to clear any potential short circuits. 

### Step 15: Solder J1 (6-pin ISP header) 
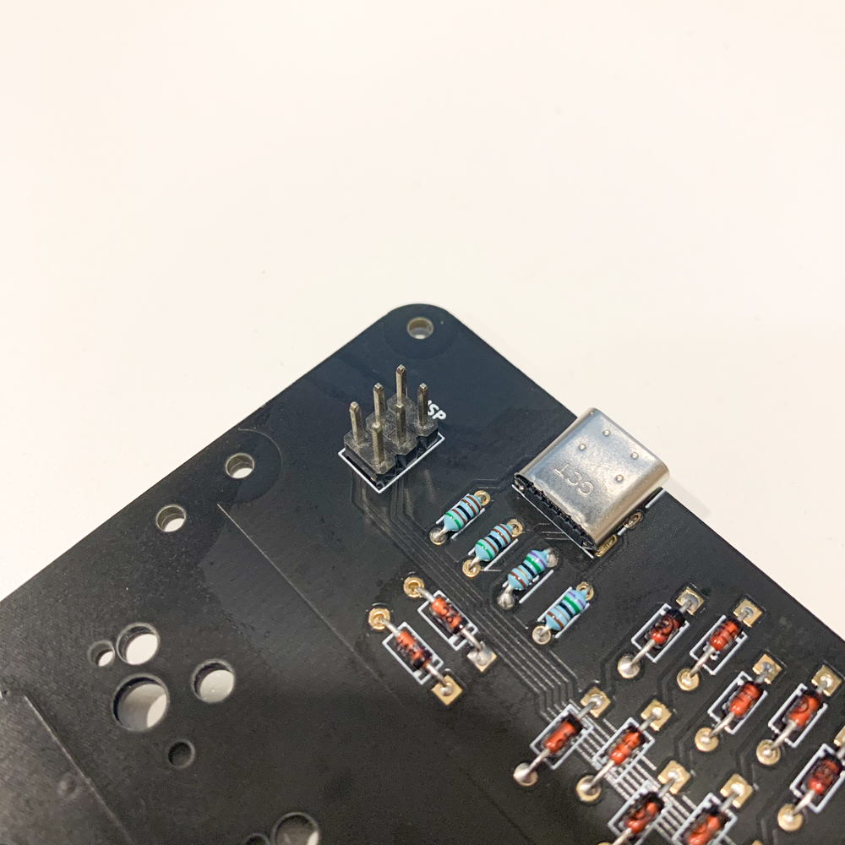
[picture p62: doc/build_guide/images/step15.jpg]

It's not necessary to trim the leads after soldering.

### Step 16: Solder rotary encoder 
It's not necessary to trim the leads after soldering.

After soldering: you can plug your keyboard into the computer. If you get an over-current warning, please go back and inspect your work. There is a short between two or more pins that is causing excess current to flow. This is usually at the USB C connector due to its fine pitch.

Your USB ports may not work after this is triggered. You will have to restart your computer to clear this error.

The Framework should be recognized by [VIA](https://caniusevia.com/). If it is not, please inspect your soldering to make sure there are no shorts and that all solder joints look good.

You should be able to turn the rotary encoder to change volume.

(my fault for not photographing rotary encoder)

### Step 17: Solder Kailh hot-swap sockets 


### Step 18: Clean your PCB with alcohol 
It is recommended that you clean the flux residue with isopropyl alcohol.

### Step 19: Assemble and install stabilizers if desired 


If you intend to use 2u spacebars, install stabilizers according to the layout you plan to use. Pictured are the two 2u spacebar configurations.

### Step 20: Assemble keyboard 




Assemble the keyboard using the provided fasteners.

Peel off any protective layer from the acrylic if present. Also check to see if all of the holes in the acrylic are clear. You can poke out the holes with an allen key if they are not clear.

There are nine long screws that go through the plate from top to bottom (nut on the bottom).

There are five long screws that go through the component section into aluminum threaded spacers from bottom to top.

The acrylic component shield is fastened into the aluminum threaded spacers using the five short screws.

If using the supplied knob from group buy, use a 1/16 inch or 1.5 mm hex key to secure the knob onto the shaft of the rotary encoder.

Install the rubber feet on the bottom of the board. Rubber feet are supplied for flat or angled positions.

### Step 21: Install switches and keycaps 


Enjoy!

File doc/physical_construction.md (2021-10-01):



# Physical construction
## Panels
The top plate, main PCB, and back plate are all panelized as one piece.
1. Snap each of these panels into their own pieces by hand
2. Using pliers, break off the mousebite tabs.
3. You can use a file or sandpaper to file down the notches left by the tabs on the three panels until smooth. I find using a nail file works great.

## Acrylic layers
There are three acrylic pieces:
- **Acrylic shield** - 1.5 mm - This is a piece of acrylic that is mounted above the components for aesthetics and minor component protection
- **Middle acrylic** - 2.5 mm - This piece sits between the keyswitch plate and main PCB
- **Bottom acrylic** - 2.0 mm - This piece sits between the main PCB and the bottom plate

**Important!**: Please check the datasheet or ask about the thickness variation/tolerance of the material that you are using. There can be a large (10%) variance in the material thickness. This is important because a total layer thickness of 3.5 mm must be maintained between the keyswitch plate and main PCB for proper switch mounting. Material thickness is also important because it determines the fastener lengths used.

Any variation from 2.5 mm in the middle acrylic layer can be made up with the silicone layer, which is often found sold in 0.1 mm increments in thickness. i.e. if your middle acrylic layer is found to be 2.8 mm thick, you can substitute the 1.0 mm silicone layer with a 0.7 mm silicone layer, etc.

## Silicone layer
There is a 1.0 mm silicone layer that sits between the keyswitch plate and middle acrylic layer. This silicone is largely optional in my opinion, but I feel like there are some nice qualities to be had with the dampened feel and sound.

If you choose to omit this piece, the middle acrylic layer will now need to be 3.5 mm thick to make up for the missing silicone. Additionally, the layer thicknesses are not strict, but there should be 3.5 mm between keyswitch plate and main PCB for switches to mount properly.

## Layers
- **Acrylic shield** - 1.5 mm [framework-acrylic-shield.dxf](/rev1/acrylic/dxf/framework-acrylic-shield.dxf) (for component section)
- **Threaded spacers** - 10 mm (for component section)
- **Top plate** - 1.6 mm
- **Silicone** - 1.0 mm - [framework-acrylic-upper.dxf](/rev1/acrylic/dxf/framework-acrylic-upper.dxf)
- **Middle acrylic** - 2.5 mm - [framework-acrylic-upper.dxf](/rev1/acrylic/dxf/framework-acrylic-upper.dxf)
- **Main PCB** - 1.6 mm
- **Bottom acrylic** - 2.0 mm - [framework-acrylic-lower.dxf](/rev1/acrylic/dxf/framework-acrylic-lower.dxf)
- **Bottom plate** - 1.6 mm

The total nominal thickness of all of these layers is 10.3 mm (excluding acrylic shield), but can vary slightly in the real world. Using 1.6 mm thick PCBs, the only critical dimension to maintain is the 3.5 mm total distance (1.0mm silicone + 2.5 mm acrylic) between the top plate and main PCB for switch mounting reasons.

## Fasteners
It is important that fasteners use a button head. This is important in the keyswitch area so that keycaps don't interfere.

- 5x **M2 x 4 mm button head** (acrylic component shield)
- 14x **M2 x 12 mm button head** (9x keyswitch plate, 5x component section)
- 9x **M2 nut** (underneath key area)
- 5x **M2 x 10 mm aluminum threaded spacer** (acrylic component shield)

The nine **M2 x 12 mm** screws in the keyswitch area should be inserted from the top, with M2 nuts on the bottom of the keyboard.

Five **M2 x 12 mm** screws are inserted from the bottom of the component area into the five **M2 x 10 mm** aluminum threaded spacers.

Five **M2 x 4 mm** screws secure the acrylic component shield onto the **M2 x 10 mm** aluminum threaded spacers.

## Rubber feet
This is largely user preference. I prefer to have a 6-7 degree tilt and have found the following to work very well for me:
- 2x [McMaster-Carr, 95495K931](https://www.mcmaster.com/95495K931-95495K819/)
- 2x [McMaster-Carr, 95495K701](https://www.mcmaster.com/95495K701-95495K811/)

## Rotary encoder knob
The rotary encoder knob should be for a 6 mm d-shaft. The biggest knob diameter should be around 25 mm before it interferes with the adjacent keycaps. This choice is user preference. The knob that I recommend is:
- [Digi-Key, OEJNI-90-4-7](https://www.digikey.ca/en/products/detail/kilo-international/OEJNI-90-4-7/5970407) Black
- [Digi-Key, OEJNI-90-3-7](https://www.digikey.ca/en/products/detail/kilo-international/OEJNI-90-3-7/5970404) Silver

## Bill of materials (electrical)
Obviously, the exact part does not matter, as long as it is functionally the same and has the same footprint. This is just an example BOM. Please reference the KiCAD project for component details.

Mfgr.                                   | Mfgr. part #         | Digi-Key part #        | Designator | Qty | Common Name
----------------------------------------|----------------------|------------------------|------------|-----|---------------------------
On Shore Technology Inc.                | ED281DT              | ED3050-5-ND            | U1         | 1   | DIP Socket, 28-Pin 0.3"
Vishay Beyschlag/Draloric/BC Components | A104K15X7RF5TAA      | 1109PHCT-ND            | C2, C3     | 2   | Ceramic capacitor, 0.1 uF 50 V
AVX Corporation                         | SA102A220JAA         | 478-2426-1-ND          | C4, C5     | 2   | Ceramic capacitor, 22 pF 200 V
ON Semiconductor                        | BZX79C3V6            | BZX79C3V6-ND           | D1, D2     | 2   | Zener diode, 500 mW 3.6V
ON Semiconductor                        | 1N4148               | 1N4148FS-ND            | D3 - D62   | 60  | Diode, 1N4148 100 V 200 mA
GCT                                     | USB4085-GF-A         | 2073-USB4085-GF-ACT-ND | J2         | 1   | USB 2.0 Type C Receptacle
Stackpole Electronics Inc               | RNMF14FTC10K0        | S10KCACT-ND            | R1         | 1   | Resistor, 10 kOhm
Stackpole Electronics Inc               | RNMF14FTC75R0        | S75CACT-ND             | R2, R3     | 2   | Resistor, 75 Ohm
Stackpole Electronics Inc               | RNF14FTD1K50         | RNF14FTD1K50CT-ND      | R4         | 1   | Resistor, 1.5 kOhm
Stackpole Electronics Inc               | RNMF14FAD5K10        | RNMF14FAD5K10CT-ND     | R5, R6     | 2   | Resistor, 5.1 kOhm
TE Connectivity ALCOSWITCH Switches     | 1825910-6            | 450-1650-ND            | SW1, SW2   | 2   | Tactile switch, SPST-NO
Fox Electronics                         | FC4STCBMF16.0-BAG200 | 631-1108-ND            | Y1         | 1   | Crystal, 16 MHz
Panasonic Electronic Components         | ECE-A1HKA4R7         | P827-ND                | C1         | 1   | Electrolytic capacitor, 4.7 uF 50V
Microchip Technology                    | ATMEGA328P-PU        | ATMEGA328P-PU-ND       | U1         | 1   | ATMega328P-PU
Harwin Inc.                             | M20-9980345          | 952-2120-ND            | J1         | 1   | Header, 6-pin 2x3
Bourns Inc.                             | PEC11R-4220F-S0024   | PEC11R-4220F-S0024-ND  | [*1]       | 1   | Rotary encoder
Kaihua Electronics Co., Ltd.            | CPG151101S11         | [*2]                   | [*1]       | 62  | Hotswap socket

[*1] There is no reference designator for this component the board, but it should be obvious which footprint it belongs to.

[*2] Digi-Key does not stock this, but it seems easy enough to find through many vendors online if you search for the part number or "kailh hotswap sockets".

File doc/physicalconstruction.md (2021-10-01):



# Physical construction
## Panels
The top plate, main PCB, and back plate are all panelized as one piece.
1. Snap each of these panels into their own pieces by hand
2. Using pliers, break off the mousebite tabs.
3. You can use a file or sandpaper to file down the notches left by the tabs on the three panels until smooth. I find using a nail file works great.

## Acrylic layers
There are three acrylic pieces:
- **Acrylic shield** - 1.5 mm - This is a piece of acrylic that is mounted above the components for aesthetics and minor component protection
- **Middle acrylic** - 2.5 mm - This piece sits between the keyswitch plate and main PCB
- **Bottom acrylic** - 2.0 mm - This piece sits between the main PCB and the bottom plate

**Important!**: Please check the datasheet or ask about the thickness variation/tolerance of the material that you are using. There can be a large (10%) variance in the material thickness. This is important because a total layer thickness of 3.5 mm must be maintained between the keyswitch plate and main PCB for proper switch mounting. Material thickness is also important because it determines the fastener lengths used.

Any variation from 2.5 mm in the middle acrylic layer can be made up with the silicone layer, which is often found sold in 0.1 mm increments in thickness. i.e. if your middle acrylic layer is found to be 2.8 mm thick, you can substitute the 1.0 mm silicone layer with a 0.7 mm silicone layer, etc.

## Silicone layer
There is a 1.0 mm silicone layer that sits between the keyswitch plate and middle acrylic layer. This silicone is largely optional in my opinion, but I feel like there are some nice qualities to be had with the dampened feel and sound.

If you choose to omit this piece, the middle acrylic layer will now need to be 3.5 mm thick to make up for the missing silicone. Additionally, the layer thicknesses are not strict, but there should be 3.5 mm between keyswitch plate and main PCB for switches to mount properly.

## Layers
- **Acrylic shield** - 1.5 mm [framework-acrylic-shield.dxf](/rev1/acrylic/dxf/framework-acrylic-shield.dxf) (for component section)
- **Threaded spacers** - 10 mm (for component section)
- **Top plate** - 1.6 mm
- **Silicone** - 1.0 mm - [framework-acrylic-upper.dxf](/rev1/acrylic/dxf/framework-acrylic-upper.dxf)
- **Middle acrylic** - 2.5 mm - [framework-acrylic-upper.dxf](/rev1/acrylic/dxf/framework-acrylic-upper.dxf)
- **Main PCB** - 1.6 mm
- **Bottom acrylic** - 2.0 mm - [framework-acrylic-lower.dxf](/rev1/acrylic/dxf/framework-acrylic-lower.dxf)
- **Bottom plate** - 1.6 mm

The total nominal thickness of all of these layers is 10.3 mm (excluding acrylic shield), but can vary slightly in the real world. Using 1.6 mm thick PCBs, the only critical dimension to maintain is the 3.5 mm total distance (1.0mm silicone + 2.5 mm acrylic) between the top plate and main PCB for switch mounting reasons.

## Fasteners
It is important that fasteners use a button head. This is important in the keyswitch area so that keycaps don't interfere.

- 5x **M2 x 4 mm button head** (acrylic component shield)
- 14x **M2 x 12 mm button head** (9x keyswitch plate, 5x component section)
- 9x **M2 nut** (underneath key area)
- 5x **M2 x 10 mm aluminum threaded spacer** (acrylic component shield)

The nine **M2 x 12 mm** screws in the keyswitch area should be inserted from the top, with M2 nuts on the bottom of the keyboard.

Five **M2 x 12 mm** screws are inserted from the bottom of the component area into the five **M2 x 10 mm** aluminum threaded spacers.

Five **M2 x 4 mm** screws secure the acrylic component shield onto the **M2 x 10 mm** aluminum threaded spacers.

## Rubber feet
This is largely user preference. I prefer to have a 6-7 degree tilt and have found the following to work very well for me:
- 2x [McMaster-Carr, 95495K931](https://www.mcmaster.com/95495K931-95495K819/)
- 2x [McMaster-Carr, 95495K701](https://www.mcmaster.com/95495K701-95495K811/)

## Rotary encoder knob
The rotary encoder knob should be for a 6 mm d-shaft. The biggest knob diameter should be around 25 mm before it interferes with the adjacent keycaps. This choice is user preference. The knob that I recommend is:
- [Digi-Key, OEJNI-90-4-7](https://www.digikey.ca/en/products/detail/kilo-international/OEJNI-90-4-7/5970407) Black
- [Digi-Key, OEJNI-90-3-7](https://www.digikey.ca/en/products/detail/kilo-international/OEJNI-90-3-7/5970404) Silver

## Bill of materials (electrical)
Obviously, the exact part does not matter, as long as it is functionally the same and has the same footprint. This is just an example BOM. Please reference the KiCAD project for component details.

Mfgr.                                   | Mfgr. part #         | Digi-Key part #        | Designator | Qty | Standard Name
----------------------------------------|----------------------|------------------------|------------|-----|---------------------------
On Shore Technology Inc.                | ED281DT              | ED3050-5-ND            | U1         | 1   | DIP IC Socket 28-Pin 0.3"
Vishay Beyschlag/Draloric/BC Components | A104K15X7RF5TAA      | 1109PHCT-ND            | C2, C3     | 2   | Ceramic Capacitor, 0.1uF 50v
AVX Corporation                         | SA102A220JAA         | 478-2426-1-ND          | C4, C5     | 2   | Ceramic Capacitor, 22pF 200v
ON Semiconductor                        | BZX79C3V6            | BZX79C3V6-ND           | D1, D2     | 2   | Zener Diode, 500mW 3.6V DO35
ON Semiconductor                        | 1N4148               | 1N4148FS-ND            | D3 - D62   | 60  | Diode, 1N4148 100V 200mA
GCT                                     | USB4085-GF-A         | 2073-USB4085-GF-ACT-ND | J2         | 1   | USB 2.0 Type C Receptacle
Stackpole Electronics Inc               | RNMF14FTC10K0        | S10KCACT-ND            | R1         | 1   | Resistor, 10 kOhms
Stackpole Electronics Inc               | RNMF14FTC75R0        | S75CACT-ND             | R2, R3     | 2   | Resistor, 75 Ohms
Stackpole Electronics Inc               | RNF14FTD1K50         | RNF14FTD1K50CT-ND      | R4         | 1   | Resistor, 1.5 kOhms
Stackpole Electronics Inc               | RNMF14FAD5K10        | RNMF14FAD5K10CT-ND     | R5, R6     | 2   | Resistor, 5.1 kOhms
TE Connectivity ALCOSWITCH Switches     | 1825910-6            | 450-1650-ND            | SW1, SW2   | 2   | 6x6x1 4-pin Push Button
Fox Electronics                         | FC4STCBMF16.0-BAG200 | 631-1108-ND            | Y1         | 1   | 16 MHz Crystal Oscillator
Panasonic Electronic Components         | ECE-A1HKA4R7         | P827-ND                | C1         | 1   | Electrolytic Capacitor, 4.7uF 50V
Microchip Technology                    | ATMEGA328P-PU        | ATMEGA328P-PU-ND       | U1         | 1   | ATMega328P-PU
Harwin Inc.                             | M20-9980345          | 952-2120-ND            | J1         | 1   | 6-pin Header Connector
Bourns Inc.                             | PEC11R-4220F-S0024   | PEC11R-4220F-S0024-ND  | [*1]       | 1   | Rotary Encoder
Kaihua Electronics Co., Ltd.            | CPG151101S11         | [*2]                   | [*1]       | 62  | Hotswap Sockets

[*1] There is no reference designator for this component the board, but it should be obvious which footprint it belongs to.

[*2] Digi-Key does not stock this, but it seems easy enough to find through many vendors online if you search for the part number or "kailh hotswap sockets".

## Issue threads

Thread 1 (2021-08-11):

A question about the zener diodes, and a mistake.

myst729, 2021-08-11:
**The issue**: In your schematic, it looks like you connect two Schottky diodes to USB D+/D-. This leads me to the wrong direction in the first place. Then I checked the BOM and find out they are Zener diodes. They are slightly different.

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

**The question**: I'm an amateur hobbyist so this question might be stupid. Your current design adopts a 16Mhz crystal, which makes the MCU runs under 5V. Then you put two Zener diodes to limit the voltage . Why not use an 8Mhz crystal so that the MCU runs under 3.3V?

stevennguyen, 2021-08-11:
Hey Leo, thanks for catching that!

Since the ATmega328P has no native USB driver, the firmware uses [V-USB](https://github.com/obdev/v-usb), which requires the higher clock speed.

stevennguyen, 2021-08-12:
Fixed issue: https://github.com/stevennguyen/framework/commit/9c14dc4136175cf56bad0931c2c7604f0b292a57

Closed 2021-08-12.

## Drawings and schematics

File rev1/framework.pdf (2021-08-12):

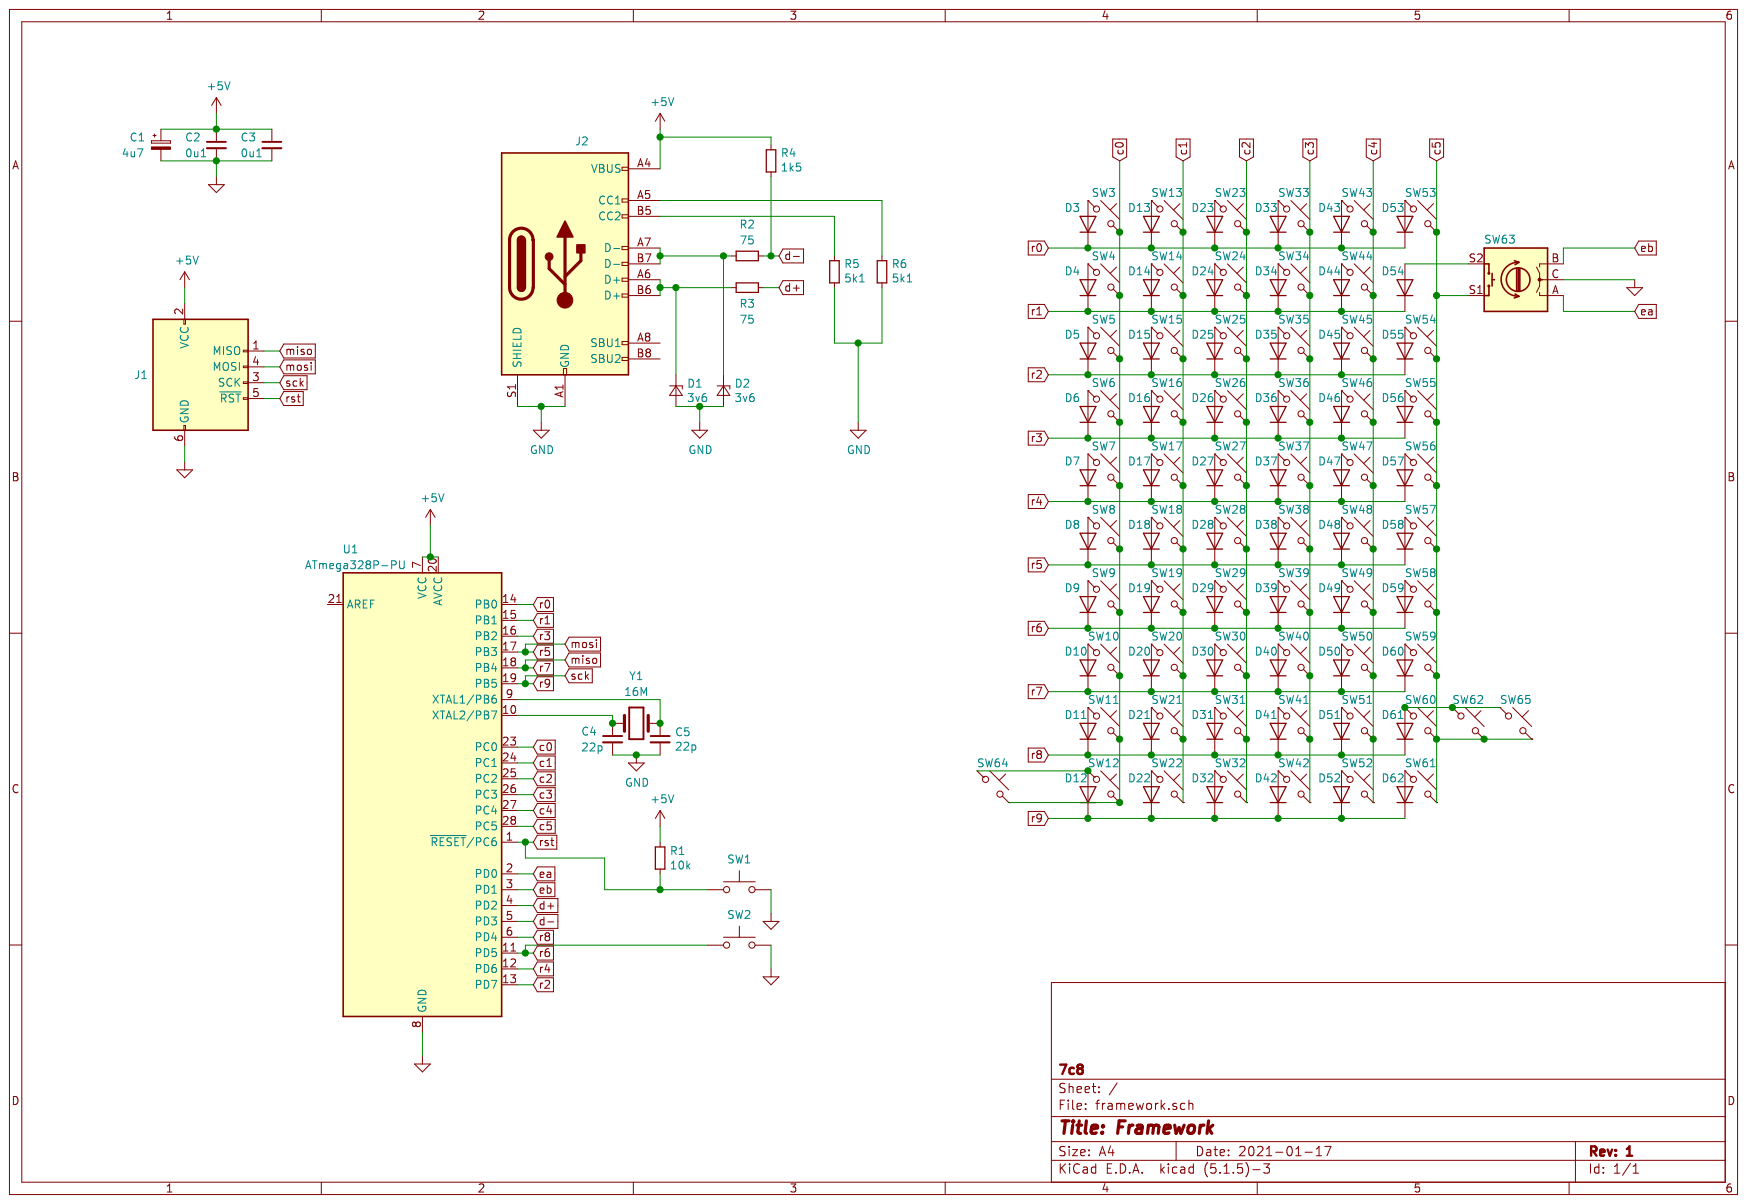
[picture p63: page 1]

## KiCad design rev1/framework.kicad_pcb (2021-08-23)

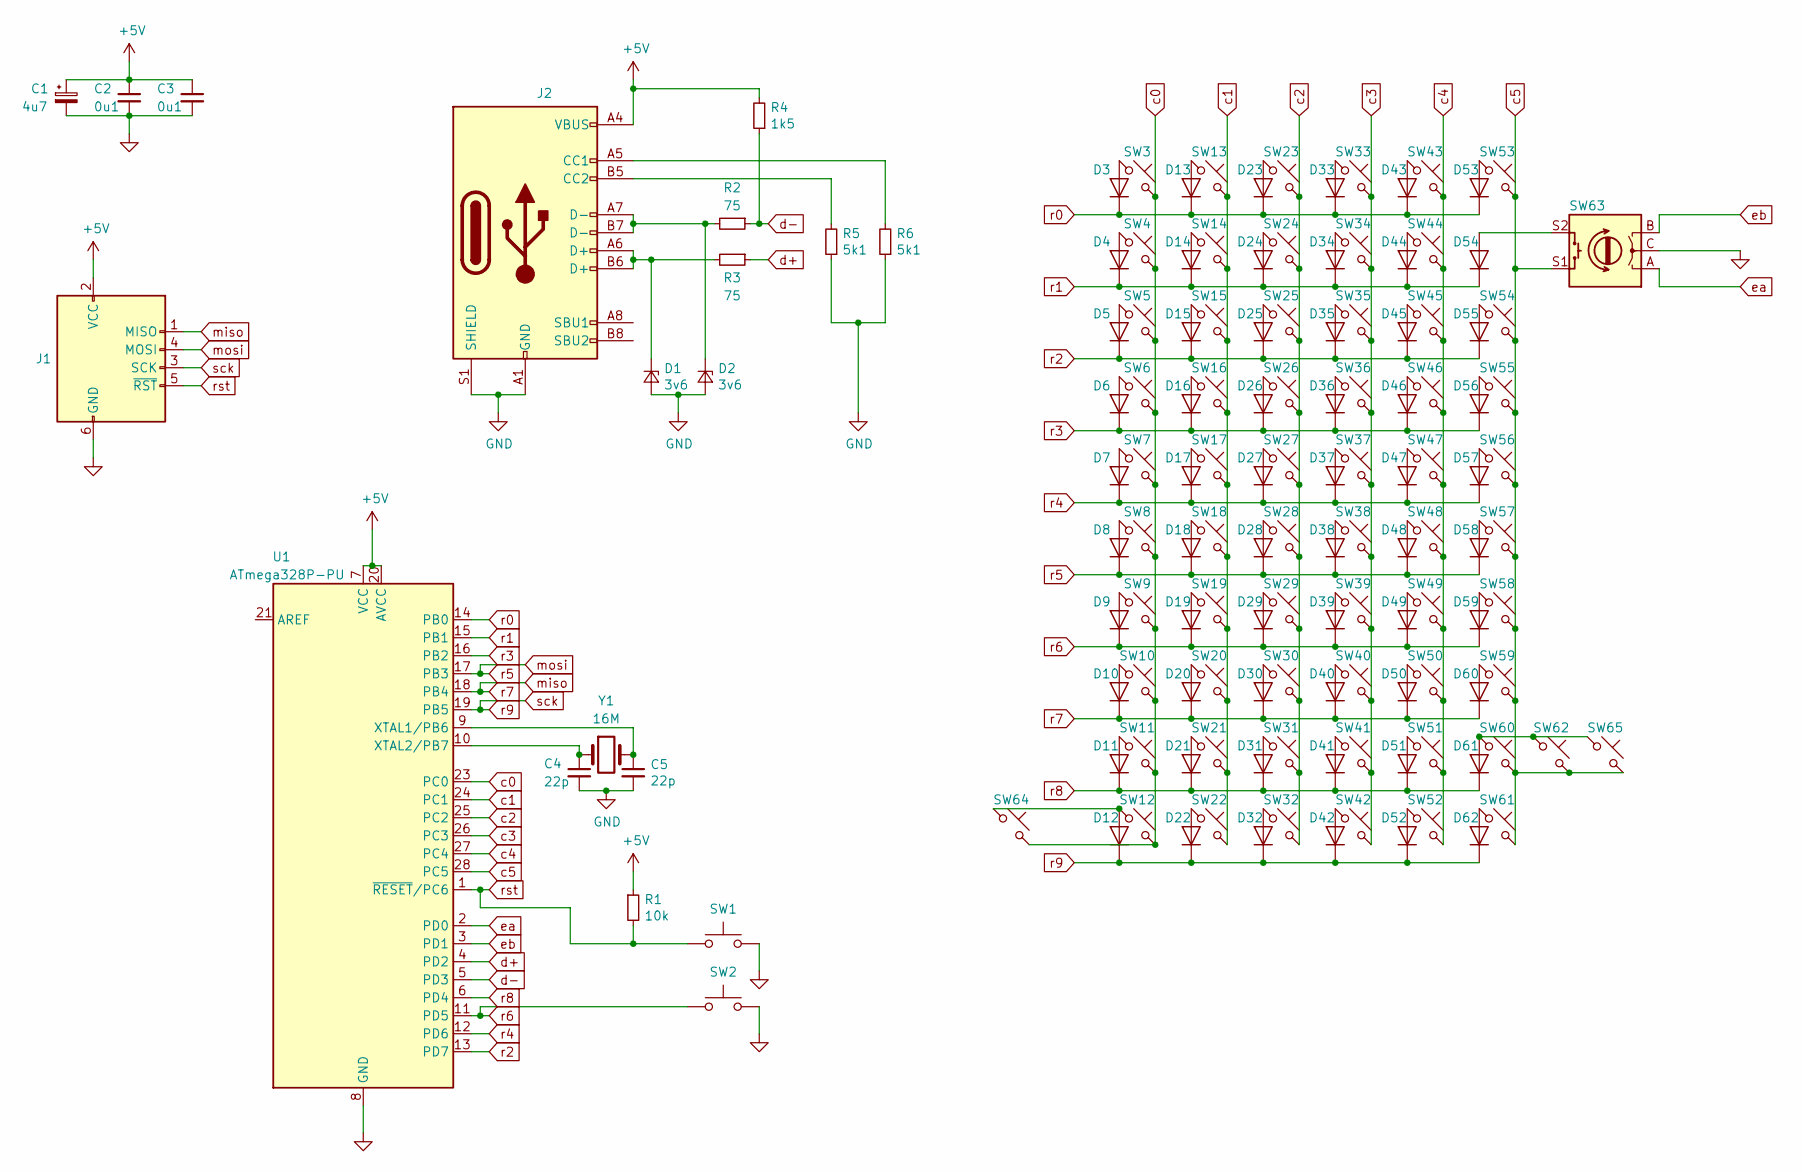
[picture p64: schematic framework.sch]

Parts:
C1: 4u7; CP_Radial_D4.0mm_P1.50mm
C2, C3: 0u1; C_Axial_L3.8mm_D2.6mm_P7.50mm_Horizontal
C4, C5: 22p; C_Axial_L3.8mm_D2.6mm_P7.50mm_Horizontal
D1, D2: 3v6; D_DO-35_SOD27_P7.62mm_Horizontal
D3, D4, D5, D6, D7, D8, D9, D10, D11, D12, D13, D14, D15, D16, D17, D18, D19, D20, D21, D22, D23, D24, D25, D26, D27, D28, D29, D30, D31, D32, D33, D34, D35, D36, D37, D38, D39, D40, D41, D42, D43, D44, D45, D46, D47, D48, D49, D50, D51, D52, D53, D54, D55, D56, D57, D58, D59, D60, D61, D62: D; D_DO-35_SOD27_P7.62mm_Horizontal
J1: AVR-ISP-6; PinHeader_2x03_P2.54mm_Vertical
J2: USB_C_Receptacle_USB2.0; USB_C_Receptacle_GCT_USB4085
R1: 10k; R_Axial_DIN0204_L3.6mm_D1.6mm_P5.08mm_Horizontal
R2, R3: 75; R_Axial_DIN0204_L3.6mm_D1.6mm_P5.08mm_Horizontal
R4: 1k5; R_Axial_DIN0207_L6.3mm_D2.5mm_P7.62mm_Horizontal
R5, R6: 5k1; R_Axial_DIN0204_L3.6mm_D1.6mm_P5.08mm_Horizontal
SW1, SW2: SW_Push; SW_PUSH_6mm_H4.3mm
SW3, SW4, SW5, SW6, SW7, SW8, SW9, SW10, SW11, SW12, SW13, SW14, SW15, SW16, SW17, SW18, SW19, SW20, SW21, SW22, SW23, SW24, SW25, SW26, SW27, SW28, SW29, SW30, SW31, SW32, SW33, SW34, SW35, SW36, SW37, SW38, SW39, SW40, SW41, SW42, SW43, SW44, SW45, SW46, SW47, SW48, SW49, SW50, SW51, SW52, SW53, SW54, SW55, SW56, SW57, SW58, SW59, SW60, SW61, SW62, SW64, SW65: SW_Push_45deg; Kailh_socket_MX_no_fsilk
SW63: Rotary_Encoder_Switch; RotaryEncoder_Alps_EC11E-Switch_Vertical_H20mm
U1: ATmega328P-PU; DIP-28_W7.62mm
Y1: 16M; Crystal_HC49-4H_Vertical

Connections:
+5V: C1.1, C2.1, C3.1, J1.2 (VCC), J2.A4 (VBUS), J2.A9 (VBUS), J2.B4 (VBUS), J2.B9 (VBUS), R1.1, R4.2, U1.7 (VCC), U1.20 (AVCC)
GND: C1.2, C2.2, C3.2, C4.2, C5.2, D1.2 (A), D2.2 (A), J1.6 (GND), J2.A1 (GND), J2.A12 (GND), J2.B1 (GND), J2.B12 (GND), J2.S1 (SHIELD), R5.1, R6.1, SW1.2, SW2.2, SW63.C, U1.8 (GND), U1.22 (GND)
unnamed: C4.1, U1.10 (XTAL2/PB7), Y1.1
unnamed: C5.1, U1.9 (XTAL1/PB6), Y1.2
unnamed: D1.1 (K), J2.A6 (D+), J2.B6 (D+), R3.2
unnamed: D2.1 (K), J2.A7 (D-), J2.B7 (D-), R2.2
unnamed: D3.2 (A), SW3.1
unnamed: D4.2 (A), SW4.1
unnamed: D5.2 (A), SW5.1
unnamed: D6.2 (A), SW6.1
unnamed: D7.2 (A), SW7.1
unnamed: D8.2 (A), SW8.1
unnamed: D9.2 (A), SW9.1
unnamed: D10.2 (A), SW10.1
unnamed: D11.2 (A), SW11.1
unnamed: D12.2 (A), SW12.1, SW64.1
unnamed: D13.2 (A), SW13.1
unnamed: D14.2 (A), SW14.1
unnamed: D15.2 (A), SW15.1
unnamed: D16.2 (A), SW16.1
unnamed: D17.2 (A), SW17.1
unnamed: D18.2 (A), SW18.1
unnamed: D19.2 (A), SW19.1
unnamed: D20.2 (A), SW20.1
unnamed: D21.2 (A), SW21.1
unnamed: D22.2 (A), SW22.1
unnamed: D23.2 (A), SW23.1
unnamed: D24.2 (A), SW24.1
unnamed: D25.2 (A), SW25.1
unnamed: D26.2 (A), SW26.1
unnamed: D27.2 (A), SW27.1
unnamed: D28.2 (A), SW28.1
unnamed: D29.2 (A), SW29.1
unnamed: D30.2 (A), SW30.1
unnamed: D31.2 (A), SW31.1
unnamed: D32.2 (A), SW32.1
unnamed: D33.2 (A), SW33.1
unnamed: D34.2 (A), SW34.1
unnamed: D35.2 (A), SW35.1
unnamed: D36.2 (A), SW36.1
unnamed: D37.2 (A), SW37.1
unnamed: D38.2 (A), SW38.1
unnamed: D39.2 (A), SW39.1
unnamed: D40.2 (A), SW40.1
unnamed: D41.2 (A), SW41.1
unnamed: D42.2 (A), SW42.1
unnamed: D43.2 (A), SW43.1
unnamed: D44.2 (A), SW44.1
unnamed: D45.2 (A), SW45.1
unnamed: D46.2 (A), SW46.1
unnamed: D47.2 (A), SW47.1
unnamed: D48.2 (A), SW48.1
unnamed: D49.2 (A), SW49.1
unnamed: D50.2 (A), SW50.1
unnamed: D51.2 (A), SW51.1
unnamed: D52.2 (A), SW52.1
unnamed: D53.2 (A), SW53.1
unnamed: D54.2 (A), SW63.S2
unnamed: D55.2 (A), SW54.1
unnamed: D56.2 (A), SW55.1
unnamed: D57.2 (A), SW56.1
unnamed: D58.2 (A), SW57.1
unnamed: D59.2 (A), SW58.1
unnamed: D60.2 (A), SW59.1
unnamed: D61.2 (A), SW60.1, SW62.1, SW65.1
unnamed: D62.2 (A), SW61.1
unnamed: J2.A5 (CC1), R6.2
unnamed: J2.B5 (CC2), R5.2
c0: SW3.2, SW4.2, SW5.2, SW6.2, SW7.2, SW8.2, SW9.2, SW10.2, SW11.2, SW12.2, SW64.2, U1.23 (PC0)
c1: SW13.2, SW14.2, SW15.2, SW16.2, SW17.2, SW18.2, SW19.2, SW20.2, SW21.2, SW22.2, U1.24 (PC1)
c2: SW23.2, SW24.2, SW25.2, SW26.2, SW27.2, SW28.2, SW29.2, SW30.2, SW31.2, SW32.2, U1.25 (PC2)
c3: SW33.2, SW34.2, SW35.2, SW36.2, SW37.2, SW38.2, SW39.2, SW40.2, SW41.2, SW42.2, U1.26 (PC3)
c4: SW43.2, SW44.2, SW45.2, SW46.2, SW47.2, SW48.2, SW49.2, SW50.2, SW51.2, SW52.2, U1.27 (PC4)
c5: SW53.2, SW54.2, SW55.2, SW56.2, SW57.2, SW58.2, SW59.2, SW60.2, SW61.2, SW62.2, SW63.S1, SW65.2, U1.28 (PC5)
d+: R3.1, U1.4 (PD2)
d-: R2.1, R4.1, U1.5 (PD3)
ea: SW63.A, U1.2 (PD0)
eb: SW63.B, U1.3 (PD1)
miso: D10.1 (K), D20.1 (K), D30.1 (K), D40.1 (K), D50.1 (K), D60.1 (K), J1.1 (MISO), U1.18 (PB4)
mosi: D8.1 (K), D18.1 (K), D28.1 (K), D38.1 (K), D48.1 (K), D58.1 (K), J1.4 (MOSI), U1.17 (PB3)
r0: D3.1 (K), D13.1 (K), D23.1 (K), D33.1 (K), D43.1 (K), D53.1 (K), U1.14 (PB0)
r1: D4.1 (K), D14.1 (K), D24.1 (K), D34.1 (K), D44.1 (K), D54.1 (K), U1.15 (PB1)
r2: D5.1 (K), D15.1 (K), D25.1 (K), D35.1 (K), D45.1 (K), D55.1 (K), U1.13 (PD7)
r3: D6.1 (K), D16.1 (K), D26.1 (K), D36.1 (K), D46.1 (K), D56.1 (K), U1.16 (PB2)
r4: D7.1 (K), D17.1 (K), D27.1 (K), D37.1 (K), D47.1 (K), D57.1 (K), U1.12 (PD6)
r6: D9.1 (K), D19.1 (K), D29.1 (K), D39.1 (K), D49.1 (K), D59.1 (K), SW2.1, U1.11 (PD5)
r8: D11.1 (K), D21.1 (K), D31.1 (K), D41.1 (K), D51.1 (K), D61.1 (K), U1.6 (PD4)
r9: D12.1 (K), D22.1 (K), D32.1 (K), D42.1 (K), D52.1 (K), D62.1 (K), J1.3 (SCK), U1.19 (PB5)
rst: J1.5 (~RST), R1.2, SW1.1, U1.1 (~RESET~/PC6)

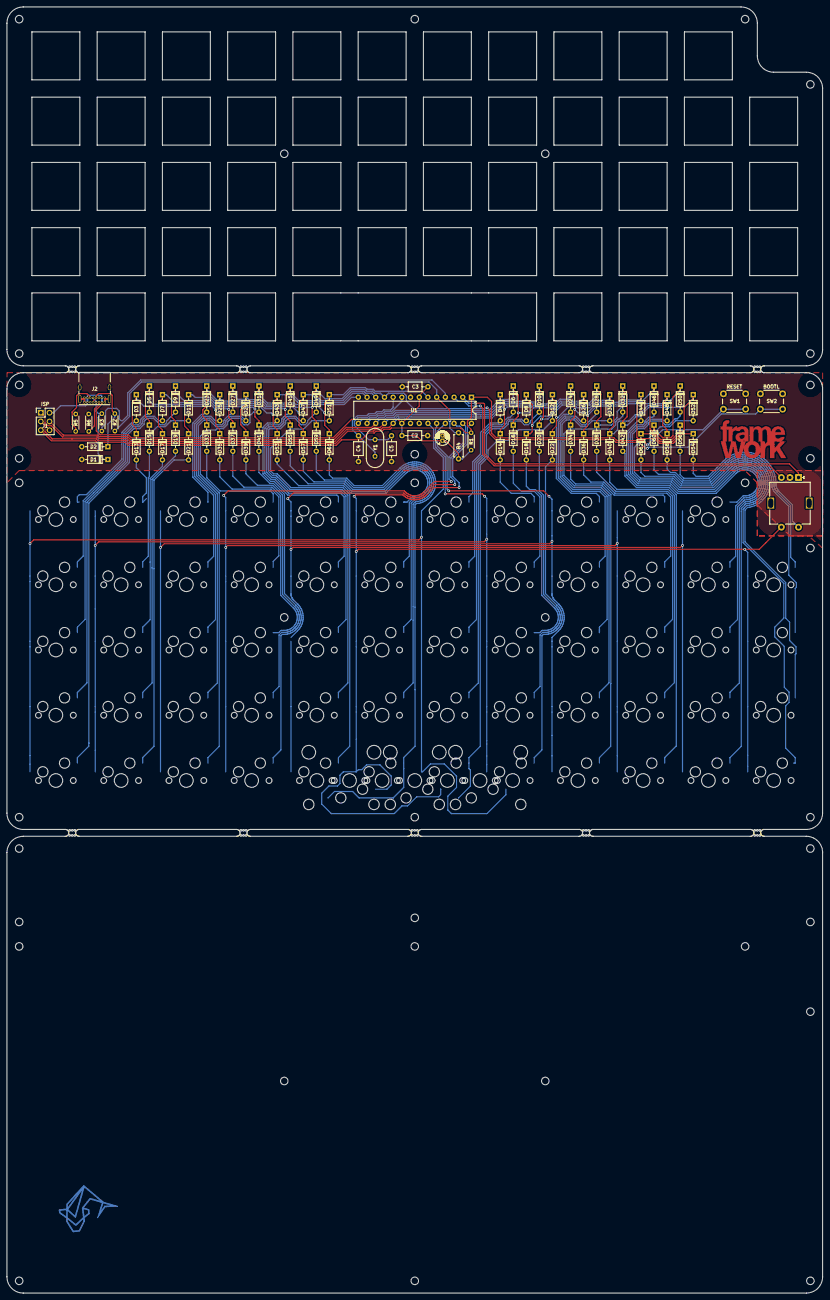
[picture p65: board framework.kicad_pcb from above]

Board: 2 copper layers, 238.1 x 375.5 mm, 152 parts (0 on the bottom side), 89 nets.

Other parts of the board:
mouse-bite-2mm-slot, mouse-bite-2mm-slot#2, mouse-bite-2mm-slot#3, mouse-bite-2mm-slot#4, mouse-bite-2mm-slot#5, mouse-bite-2mm-slot#6, mouse-bite-2mm-slot#7, mouse-bite-2mm-slot#8, mouse-bite-2mm-slot#9, mouse-bite-2mm-slot#10: VAL**; mouse-bite-2mm-slot

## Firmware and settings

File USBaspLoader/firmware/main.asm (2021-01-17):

main.elf:     file format elf32-avr

SYMBOL TABLE:
00800100 l    d  .data	00000000 .data
00007000 l    d  .text	00000000 .text
00800106 l    d  .bss	00000000 .bss
0080013b l    d  .noinit	00000000 .noinit
00000000 l    d  .comment	00000000 .comment
00000000 l    d  .note.gnu.avr.deviceinfo	00000000 .note.gnu.avr.deviceinfo
00000000 l    d  .debug_aranges	00000000 .debug_aranges
00000000 l    d  .debug_info	00000000 .debug_info
00000000 l    d  .debug_abbrev	00000000 .debug_abbrev
00000000 l    d  .debug_line	00000000 .debug_line
00000000 l    d  .debug_frame	00000000 .debug_frame
00000000 l    d  .debug_str	00000000 .debug_str
00000000 l    d  .debug_loc	00000000 .debug_loc
00000000 l    d  .debug_ranges	00000000 .debug_ranges
00000000 l    d  .debug_macro	00000000 .debug_macro
00000000 l    df *ABS*	00000000 main.c
0000003e l       *ABS*	00000000 __SP_H__
0000003d l       *ABS*	00000000 __SP_L__
0000003f l       *ABS*	00000000 __SREG__
00000000 l       *ABS*	00000000 __tmp_reg__
00000001 l       *ABS*	00000000 __zero_reg__
000070f4 l       .text	00000000 __BOOTLOADERENTRY_FROMSOFTWARE__bootup_investigate_RAMEND_done6
000070f2 l       .text	00000000 __BOOTLOADERENTRY_FROMSOFTWARE__bootup_investigate_RAMEND_mismatch6
0080013c l     O .noinit	00000001 __BOOTLOADERENTRY_FROMSOFTWARE__bootup_RAMEND_doesmatch
0080013b l     O .noinit	00000001 __BOOTLOADERENTRY_FROMSOFTWARE__bootup_MCUCSR
00800102 l     O .data	00000004 signatureBytes
0080010f l     O .bss	00000001 stayinloader
00007440 l       .text	00000000 _mywait_sleeploop241
000074a6 l       .text	00000000 _mywait_sleeploop364
00800110 l     O .bss	00000001 usbMsgFlags
00800106 l     O .bss	00000004 replyBuffer.2212
0080010d l     O .bss	00000002 currentAddress
0080010c l     O .bss	00000001 bytesRemaining
0080010b l     O .bss	00000001 isLastPage
0080010a l     O .bss	00000001 currentRequest
00800100 l     O .data	00000001 usbMsgLen
00000000 l    df *ABS*	00000000 _clear_bss.o
0000711c l       .text	00000000 .do_clear_bss_start
0000711a l       .text	00000000 .do_clear_bss_loop
00000000 l    df *ABS*	00000000 usbdrv/usbdrvasm.o
0000714c l       .text	00000000 usbCrcLoopEntry
0000713a l       .text	00000000 usbCrcByteLoop
0000713e l       .text	00000000 usbCrcBitLoop
00007148 l       .text	00000000 usbCrcNoXor
00007150 l       .text	00000000 usbCrcReady
00007162 l       .text	00000000 waitForJ
00007168 l       .text	00000000 waitForK
00007182 l       .text	00000000 foundK
00007294 l       .text	00000000 sofError
0000719c l       .text	00000000 haveTwoBitsK
0000722a l       .text	00000000 rxbit1
000071b8 l       .text	00000000 unstuff6
00007200 l       .text	00000000 didUnstuff6
000071c4 l       .text	00000000 unstuff7
0000720e l       .text	00000000 didUnstuff7
000071d0 l       .text	00000000 unstuffEven
0000724e l       .text	00000000 se0
00007226 l       .text	00000000 didUnstuffE
000071e0 l       .text	00000000 unstuffOdd
0000723a l       .text	00000000 didUnstuffO
000071f0 l       .text	00000000 rxByteLoop
000071fc l       .text	00000000 skipLeap
00007216 l       .text	00000000 rxBitLoop
00007246 l       .text	00000000 overflow
0000724a l       .text	00000000 ignorePacket
0000727c l       .text	00000000 storeTokenAndReturn
0000729e l       .text	00000000 handleData
000072c8 l       .text	00000000 handleIn
0000727c l       .text	00000000 handleSetupOrOut
00007280 l       .text	00000000 doReturn
000072fc l       .text	00000000 sendNakAndReti
00007300 l       .text	00000000 sendAckAndReti
00007302 l       .text	00000000 sendCntAndReti
0000730a l       .text	00000000 usbSendAndReti
000072e4 l       .text	00000000 bitstuffN
00007324 l       .text	00000000 didStuffN
000072f0 l       .text	00000000 bitstuff6
00007332 l       .text	00000000 didStuff6
000072f8 l       .text	00000000 bitstuff7
0000733e l       .text	00000000 didStuff7
00007304 l       .text	00000000 sendX3AndReti
00007318 l       .text	00000000 txByteLoop
0000731a l       .text	00000000 txBitLoop
00007366 l       .text	00000000 skipAddrAssign
00007376 l       .text	00000000 se0Delay
00000000 l    df *ABS*	00000000 _exit.o
00007882 l       .text	00000000 __stop_program
00007098 g     O .text	00000012 usbDescriptorDevice
00007126  w      .text	00000000 __vector_22
00007866 g       .text	00000000 eeprom_write_r18
0000715a g     F .text	00000000 __vector_1
00800111 g     O .bss	0000000b usbTxBuf
00000000 g       *ABS*	00000000 nullVector
0000ffa0 g       *ABS*	00000000 __DATA_REGION_LENGTH__
00007086 g       .text	00000000 __trampolines_start
00007884 g       .text	00000000 _etext
000070d4 g     O .text	00000004 usbDescriptorString0
00007126  w      .text	00000000 __vector_24
00007126  w      .text	00000000 __vector_12
00007126 g       .text	00000000 __bad_interrupt
0000788a g       *ABS*	00000000 __data_load_end
00007126  w      .text	00000000 __vector_6
00007128 g       .text	00000000 usbCrc16
00007086 g       .text	00000000 __trampolines_end
00007126  w      .text	00000000 __vector_3
000070e4 g     F .text	00000018 __BOOTLOADERENTRY_FROMSOFTWARE__bootup_investigate_RAMEND
00007126  w      .text	00000000 __vector_23
00007884 g       *ABS*	00000000 __data_load_start
000070d8 g       .text	00000000 __dtors_end
0080013b g       .bss	00000000 __bss_end
00000400 g       *ABS*	00000000 __LOCK_REGION_LENGTH__
00007126  w      .text	00000000 __vector_25
00007068 g     O .text	0000001e bootloader__do_spm
00007864 g     F .text	0000001c eeprom_write_byte
00007126  w      .text	00000000 __vector_11
000070d8  w      .text	00000000 __init
00007126  w      .text	00000000 __vector_13
00007152 g       .text	00000000 usbCrc16Append
00007126  w      .text	00000000 __vector_17
00007126  w      .text	00000000 __vector_19
00007126  w      .text	00000000 __vector_7
00007086 g     O .text	00000012 usbDescriptorConfiguration
00007112 g       .text	00000010 .hidden __do_clear_bss
0080011c g     O .bss	00000001 usbDeviceAddr
00810000 g       .comment	00000000 __eeprom_end
0080011d g     O .bss	00000001 usbRxToken
00007000 g       .text	00000000 __vectors
00007854 g     F .text	00000010 eeprom_read_byte
00800106 g       .data	00000000 __data_end
000070b8 g     O .text	0000001c usbDescriptorStringVendor
0080011e g     O .bss	00000001 usbInputBufOffset
00007000  w      .text	00000000 __vector_default
00007126  w      .text	00000000 __vector_5
00000400 g       *ABS*	00000000 __SIGNATURE_REGION_LENGTH__
000070d8 g       .text	00000000 __ctors_start
000070fc g       .text	00000016 .hidden __do_copy_data
00007382 g     F .text	000000ac usbFunctionSetup_USBASP_FUNC_TRANSMIT
00800106 g       .bss	00000000 __bss_start
0000742e g     F .text	00000426 main
00007126  w      .text	00000000 __vector_4
00800101 g     O .data	00000001 usbTxLen
00000000  w      *ABS*	00000000 __heap_end
00007126  w      .text	00000000 __vector_9
00007126  w      .text	00000000 __vector_2
00000400 g       *ABS*	00000000 __USER_SIGNATURE_REGION_LENGTH__
0080011f g     O .bss	00000002 usbMsgPtr
00007126  w      .text	00000000 __vector_21
00007126  w      .text	00000000 __vector_15
00800121 g     O .bss	00000001 usbRxLen
000070d8 g       .text	00000000 __dtors_start
000070d8 g       .text	00000000 __ctors_end
000008ff  w      *ABS*	00000000 __stack
00800122 g     O .bss	00000001 usbNewDeviceAddr
00800106 g       .data	00000000 _edata
0080013d g       .noinit	00000000 _end
00007126  w      .text	00000000 __vector_8
00007880  w      .text	00000000 .hidden exit
00800123 g     O .bss	00000001 usbCurrentTok
000070aa g     O .text	0000000e usbDescriptorStringDevice
00010000 g       *ABS*	00000000 __EEPROM_REGION_LENGTH__
00007880 g       .text	00000000 .hidden _exit
00800124 g     O .bss	00000001 usbConfiguration
00007126  w      .text	00000000 __vector_14
00007126  w      .text	00000000 __vector_10
00800125 g     O .bss	00000016 usbRxBuf
00007126  w      .text	00000000 __vector_16
00800100 g       .data	00000000 __data_start
00007126  w      .text	00000000 __vector_18
00000400 g       *ABS*	00000000 __FUSE_REGION_LENGTH__
00020000 g       *ABS*	00000000 __TEXT_REGION_LENGTH__
00007126  w      .text	00000000 __vector_20



Disassembly of section .text:

00007000 <__vectors>:
    7000:	6b c0       	rjmp	.+214    	; 0x70d8 <__ctors_end>
    7002:	00 00       	nop
    7004:	aa c0       	rjmp	.+340    	; 0x715a <__vector_1>
    7006:	00 00       	nop
    7008:	8e c0       	rjmp	.+284    	; 0x7126 <__bad_interrupt>
    700a:	00 00       	nop
    700c:	8c c0       	rjmp	.+280    	; 0x7126 <__bad_interrupt>
    700e:	00 00       	nop
    7010:	8a c0       	rjmp	.+276    	; 0x7126 <__bad_interrupt>
    7012:	00 00       	nop
    7014:	88 c0       	rjmp	.+272    	; 0x7126 <__bad_interrupt>
    7016:	00 00       	nop
    7018:	86 c0       	rjmp	.+268    	; 0x7126 <__bad_interrupt>
    701a:	00 00       	nop
    701c:	84 c0       	rjmp	.+264    	; 0x7126 <__bad_interrupt>
    701e:	00 00       	nop
    7020:	82 c0       	rjmp	.+260    	; 0x7126 <__bad_interrupt>
    7022:	00 00       	nop
    7024:	80 c0       	rjmp	.+256    	; 0x7126 <__bad_interrupt>
    7026:	00 00       	nop
    7028:	7e c0       	rjmp	.+252    	; 0x7126 <__bad_interrupt>
    702a:	00 00       	nop
    702c:	7c c0       	rjmp	.+248    	; 0x7126 <__bad_interrupt>
    702e:	00 00       	nop
    7030:	7a c0       	rjmp	.+244    	; 0x7126 <__bad_interrupt>
    7032:	00 00       	nop
    7034:	78 c0       	rjmp	.+240    	; 0x7126 <__bad_interrupt>
    7036:	00 00       	nop
    7038:	76 c0       	rjmp	.+236    	; 0x7126 <__bad_interrupt>
    703a:	00 00       	nop
    703c:	74 c0       	rjmp	.+232    	; 0x7126 <__bad_interrupt>
    703e:	00 00       	nop
    7040:	72 c0       	rjmp	.+228    	; 0x7126 <__bad_interrupt>
    7042:	00 00       	nop
    7044:	70 c0       	rjmp	.+224    	; 0x7126 <__bad_interrupt>
    7046:	00 00       	nop
    7048:	6e c0       	rjmp	.+220    	; 0x7126 <__bad_interrupt>
    704a:	00 00       	nop
    704c:	6c c0       	rjmp	.+216    	; 0x7126 <__bad_interrupt>
    704e:	00 00       	nop
    7050:	6a c0       	rjmp	.+212    	; 0x7126 <__bad_interrupt>
    7052:	00 00       	nop
    7054:	68 c0       	rjmp	.+208    	; 0x7126 <__bad_interrupt>
    7056:	00 00       	nop
    7058:	66 c0       	rjmp	.+204    	; 0x7126 <__bad_interrupt>
    705a:	00 00       	nop
    705c:	64 c0       	rjmp	.+200    	; 0x7126 <__bad_interrupt>
    705e:	00 00       	nop
    7060:	62 c0       	rjmp	.+196    	; 0x7126 <__bad_interrupt>
    7062:	00 00       	nop
    7064:	60 c0       	rjmp	.+192    	; 0x7126 <__bad_interrupt>
	...

00007068 <bootloader__do_spm>:
    7068:	ec 2d fd 2d b7 b6 b0 fc fd cf 27 bf e8 95 b7 b6     .-.-......'.....
    7078:	b0 fc fd cf 21 e1 b7 b6 b6 fc f4 cf 08 95           ....!.........

00007086 <usbDescriptorConfiguration>:
    7086:	09 02 12 00 01 01 00 80 32 09 04 00 00 00 00 00     ........2.......
	...

00007098 <usbDescriptorDevice>:
    7098:	12 01 10 01 ff 00 00 08 c0 16 dc 05 02 01 01 02     ................
    70a8:	00 01                                               ..

000070aa <usbDescriptorStringDevice>:
    70aa:	0e 03 55 00 53 00 42 00 61 00 73 00 70 00           ..U.S.B.a.s.p.

000070b8 <usbDescriptorStringVendor>:
    70b8:	1c 03 77 00 77 00 77 00 2e 00 66 00 69 00 73 00     ..w.w.w...f.i.s.
    70c8:	63 00 68 00 6c 00 2e 00 64 00 65 00                 c.h.l...d.e.

000070d4 <usbDescriptorString0>:
    70d4:	04 03 09 04                                         ....

000070d8 <__ctors_end>:
    70d8:	11 24       	eor	r1, r1
    70da:	1f be       	out	0x3f, r1	; 63
    70dc:	cf ef       	ldi	r28, 0xFF	; 255
    70de:	d8 e0       	ldi	r29, 0x08	; 8
    70e0:	de bf       	out	0x3e, r29	; 62
    70e2:	cd bf       	out	0x3d, r28	; 61

000070e4 <__BOOTLOADERENTRY_FROMSOFTWARE__bootup_investigate_RAMEND>:
/* ------------------------------------------------------------------------ */

#if (HAVE_BOOTLOADERENTRY_FROMSOFTWARE)
void __attribute__ ((section(".init3"),naked,used,no_instrument_function)) __BOOTLOADERENTRY_FROMSOFTWARE__bootup_investigate_RAMEND(void);
void __BOOTLOADERENTRY_FROMSOFTWARE__bootup_investigate_RAMEND(void) {
  asm volatile (
    70e4:	24 b7       	in	r18, 0x34	; 52
    70e6:	d8 e0       	ldi	r29, 0x08	; 8
    70e8:	ce ef       	ldi	r28, 0xFE	; 254
    70ea:	39 91       	ld	r19, Y+
    70ec:	38 33       	cpi	r19, 0x38	; 56
    70ee:	39 91       	ld	r19, Y+
    70f0:	09 f0       	breq	.+2      	; 0x70f4 <__BOOTLOADERENTRY_FROMSOFTWARE__bootup_investigate_RAMEND_done6>

000070f2 <__BOOTLOADERENTRY_FROMSOFTWARE__bootup_investigate_RAMEND_mismatch6>:
    70f2:	3f ef       	ldi	r19, 0xFF	; 255

000070f4 <__BOOTLOADERENTRY_FROMSOFTWARE__bootup_investigate_RAMEND_done6>:
    70f4:	30 93 3c 01 	sts	0x013C, r19	; 0x80013c <__BOOTLOADERENTRY_FROMSOFTWARE__bootup_RAMEND_doesmatch>
    70f8:	20 93 3b 01 	sts	0x013B, r18	; 0x80013b <__BOOTLOADERENTRY_FROMSOFTWARE__bootup_MCUCSR>

000070fc <__do_copy_data>:
    70fc:	11 e0       	ldi	r17, 0x01	; 1
    70fe:	a0 e0       	ldi	r26, 0x00	; 0
    7100:	b1 e0       	ldi	r27, 0x01	; 1
    7102:	e4 e8       	ldi	r30, 0x84	; 132
    7104:	f8 e7       	ldi	r31, 0x78	; 120
    7106:	02 c0       	rjmp	.+4      	; 0x710c <__do_copy_data+0x10>
    7108:	05 90       	lpm	r0, Z+
    710a:	0d 92       	st	X+, r0
    710c:	a6 30       	cpi	r26, 0x06	; 6
    710e:	b1 07       	cpc	r27, r17
    7110:	d9 f7       	brne	.-10     	; 0x7108 <__do_copy_data+0xc>

00007112 <__do_clear_bss>:
    7112:	21 e0       	ldi	r18, 0x01	; 1
    7114:	a6 e0       	ldi	r26, 0x06	; 6
    7116:	b1 e0       	ldi	r27, 0x01	; 1
    7118:	01 c0       	rjmp	.+2      	; 0x711c <.do_clear_bss_start>

0000711a <.do_clear_bss_loop>:
    711a:	1d 92       	st	X+, r1

0000711c <.do_clear_bss_start>:
    711c:	ab 33       	cpi	r26, 0x3B	; 59
    711e:	b2 07       	cpc	r27, r18
    7120:	e1 f7       	brne	.-8      	; 0x711a <.do_clear_bss_loop>
    7122:	85 d1       	rcall	.+778    	; 0x742e <main>
    7124:	ad c3       	rjmp	.+1882   	; 0x7880 <_exit>

00007126 <__bad_interrupt>:
    7126:	6c cf       	rjmp	.-296    	; 0x7000 <__vectors>

00007128 <usbCrc16>:
;   poly    r20+r21
;   scratch r23
;   resCrc  r24+r25 / r16+r17
;   ptr     X / Z
usbCrc16:
    mov     ptrL, argPtrL
    7128:	a8 2f       	mov	r26, r24
    mov     ptrH, argPtrH
    712a:	b9 2f       	mov	r27, r25
    ldi     resCrcL, 0
    712c:	80 e0       	ldi	r24, 0x00	; 0
    ldi     resCrcH, 0
    712e:	90 e0       	ldi	r25, 0x00	; 0
    ldi     polyL, lo8(0xa001)
    7130:	41 e0       	ldi	r20, 0x01	; 1
    ldi     polyH, hi8(0xa001)
    7132:	50 ea       	ldi	r21, 0xA0	; 160
    com     argLen      ; argLen = -argLen - 1: modified loop to ensure that carry is set
    7134:	60 95       	com	r22
    ldi     bitCnt, 0   ; loop counter with starnd condition = end condition
    7136:	30 e0       	ldi	r19, 0x00	; 0
    rjmp    usbCrcLoopEntry
    7138:	09 c0       	rjmp	.+18     	; 0x714c <usbCrcLoopEntry>

0000713a <usbCrcByteLoop>:
usbCrcByteLoop:
    ld      byte, ptr+
    713a:	2d 91       	ld	r18, X+
    eor     resCrcL, byte
    713c:	82 27       	eor	r24, r18

0000713e <usbCrcBitLoop>:
usbCrcBitLoop:
    ror     resCrcH     ; carry is always set here (see brcs jumps to here)
    713e:	97 95       	ror	r25
    ror     resCrcL
    7140:	87 95       	ror	r24
    brcs    usbCrcNoXor
    7142:	10 f0       	brcs	.+4      	; 0x7148 <usbCrcNoXor>
    eor     resCrcL, polyL
    7144:	84 27       	eor	r24, r20
    eor     resCrcH, polyH
    7146:	95 27       	eor	r25, r21

00007148 <usbCrcNoXor>:
usbCrcNoXor:
    subi    bitCnt, 224 ; (8 * 224) % 256 = 0; this loop iterates 8 times
    7148:	30 5e       	subi	r19, 0xE0	; 224
    brcs    usbCrcBitLoop
    714a:	c8 f3       	brcs	.-14     	; 0x713e <usbCrcBitLoop>

0000714c <usbCrcLoopEntry>:
usbCrcLoopEntry:
    subi    argLen, -1
    714c:	6f 5f       	subi	r22, 0xFF	; 255
    brcs    usbCrcByteLoop
    714e:	a8 f3       	brcs	.-22     	; 0x713a <usbCrcByteLoop>

00007150 <usbCrcReady>:
usbCrcReady:
    ret
    7150:	08 95       	ret

00007152 <usbCrc16Append>:

#endif /* USB_USE_FAST_CRC */

; extern unsigned usbCrc16Append(unsigned char *data, unsigned char len);
usbCrc16Append:
    rcall   usbCrc16
    7152:	ea df       	rcall	.-44     	; 0x7128 <usbCrc16>
    st      ptr+, resCrcL
    7154:	8d 93       	st	X+, r24
    st      ptr+, resCrcH
    7156:	9d 93       	st	X+, r25
    ret
    7158:	08 95       	ret

0000715a <__vector_1>:
; Numbers in brackets are clocks counted from center of last sync bit
; when instruction starts

USB_INTR_VECTOR:
;order of registers pushed: YL, SREG YH, [sofError], bitcnt, shift, x1, x2, x3, x4, cnt
    push    YL                  ;[-25] push only what is necessary to sync with edge ASAP
    715a:	cf 93       	push	r28
    in      YL, SREG            ;[-23]
    715c:	cf b7       	in	r28, 0x3f	; 63
    push    YL                  ;[-22]
    715e:	cf 93       	push	r28
    push    YH                  ;[-20]
    7160:	df 93       	push	r29

00007162 <waitForJ>:
;sync up with J to K edge during sync pattern -- use fastest possible loops
;The first part waits at most 1 bit long since we must be in sync pattern.
;YL is guarenteed to be < 0x80 because I flag is clear. When we jump to
;waitForJ, ensure that this prerequisite is met.
waitForJ:
    inc     YL
    7162:	c3 95       	inc	r28
    sbis    USBIN, USBMINUS
    7164:	4b 9b       	sbis	0x09, 3	; 9
    brne    waitForJ        ; just make sure we have ANY timeout
    7166:	e9 f7       	brne	.-6      	; 0x7162 <waitForJ>

00007168 <waitForK>:
waitForK:
;The following code results in a sampling window of < 1/4 bit which meets the spec.
    sbis    USBIN, USBMINUS     ;[-15]
    7168:	4b 9b       	sbis	0x09, 3	; 9
    rjmp    foundK              ;[-14]
    716a:	0b c0       	rjmp	.+22     	; 0x7182 <foundK>
    sbis    USBIN, USBMINUS
    716c:	4b 9b       	sbis	0x09, 3	; 9
    rjmp    foundK
    716e:	09 c0       	rjmp	.+18     	; 0x7182 <foundK>
    sbis    USBIN, USBMINUS
    7170:	4b 9b       	sbis	0x09, 3	; 9
    rjmp    foundK
    7172:	07 c0       	rjmp	.+14     	; 0x7182 <foundK>
    sbis    USBIN, USBMINUS
    7174:	4b 9b       	sbis	0x09, 3	; 9
    rjmp    foundK
    7176:	05 c0       	rjmp	.+10     	; 0x7182 <foundK>
    sbis    USBIN, USBMINUS
    7178:	4b 9b       	sbis	0x09, 3	; 9
    rjmp    foundK
    717a:	03 c0       	rjmp	.+6      	; 0x7182 <foundK>
    sbis    USBIN, USBMINUS
    717c:	4b 9b       	sbis	0x09, 3	; 9
    rjmp    foundK
    717e:	01 c0       	rjmp	.+2      	; 0x7182 <foundK>
    sts     usbSofCount, YL
#endif  /* USB_COUNT_SOF */
#ifdef USB_SOF_HOOK
    USB_SOF_HOOK
#endif
    rjmp    sofError
    7180:	89 c0       	rjmp	.+274    	; 0x7294 <sofError>

00007182 <foundK>:
foundK:                         ;[-12]
;{3, 5} after falling D- edge, average delay: 4 cycles [we want 5 for center sampling]
;we have 1 bit time for setup purposes, then sample again. Numbers in brackets
;are cycles from center of first sync (double K) bit after the instruction
    push    bitcnt              ;[-12]
    7182:	6f 93       	push	r22
;   [---]                       ;[-11]
    lds     YL, usbInputBufOffset;[-10]
    7184:	c0 91 1e 01 	lds	r28, 0x011E	; 0x80011e <usbInputBufOffset>
;   [---]                       ;[-9]
    clr     YH                  ;[-8]
    7188:	dd 27       	eor	r29, r29
    subi    YL, lo8(-(usbRxBuf));[-7] [rx loop init]
    718a:	cb 5d       	subi	r28, 0xDB	; 219
    sbci    YH, hi8(-(usbRxBuf));[-6] [rx loop init]
    718c:	de 4f       	sbci	r29, 0xFE	; 254
    push    shift               ;[-5]
    718e:	2f 93       	push	r18
;   [---]                       ;[-4]
    ldi     bitcnt, 0x55        ;[-3] [rx loop init]
    7190:	65 e5       	ldi	r22, 0x55	; 85
    sbis    USBIN, USBMINUS     ;[-2] we want two bits K (sample 2 cycles too early)
    7192:	4b 9b       	sbis	0x09, 3	; 9
    rjmp    haveTwoBitsK        ;[-1]
    7194:	03 c0       	rjmp	.+6      	; 0x719c <haveTwoBitsK>
    pop     shift               ;[0] undo the push from before
    7196:	2f 91       	pop	r18
    pop     bitcnt              ;[2] undo the push from before
    7198:	6f 91       	pop	r22
    rjmp    waitForK            ;[4] this was not the end of sync, retry
    719a:	e6 cf       	rjmp	.-52     	; 0x7168 <waitForK>

0000719c <haveTwoBitsK>:

;----------------------------------------------------------------------------
; push more registers and initialize values while we sample the first bits:
;----------------------------------------------------------------------------
haveTwoBitsK:
    push    x1              ;[1]
    719c:	0f 93       	push	r16
    push    x2              ;[3]
    719e:	1f 93       	push	r17
    push    x3              ;[5]
    71a0:	4f 93       	push	r20
    ldi     shift, 0        ;[7]
    71a2:	20 e0       	ldi	r18, 0x00	; 0
    ldi     x3, 1<<4        ;[8] [rx loop init] first sample is inverse bit, compensate that
    71a4:	40 e1       	ldi	r20, 0x10	; 16
    push    x4              ;[9] == leap
    71a6:	5f 93       	push	r21

    in      x1, USBIN       ;[11] <-- sample bit 0
    71a8:	09 b1       	in	r16, 0x09	; 9
    andi    x1, USBMASK     ;[12]
    71aa:	0c 70       	andi	r16, 0x0C	; 12
    bst     x1, USBMINUS    ;[13]
    71ac:	03 fb       	bst	r16, 3
    bld     shift, 7        ;[14]
    71ae:	27 f9       	bld	r18, 7
    push    cnt             ;[15]
    71b0:	3f 93       	push	r19
    ldi     leap, 0         ;[17] [rx loop init]
    71b2:	50 e0       	ldi	r21, 0x00	; 0
    ldi     cnt, USB_BUFSIZE;[18] [rx loop init]
    71b4:	3b e0       	ldi	r19, 0x0B	; 11
    rjmp    rxbit1          ;[19] arrives at [21]
    71b6:	39 c0       	rjmp	.+114    	; 0x722a <rxbit1>

000071b8 <unstuff6>:

; duration of unstuffing code should be 10.66666667 cycles. We adjust "leap"
; accordingly to approximate this value in the long run.
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

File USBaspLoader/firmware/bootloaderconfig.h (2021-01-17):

/* Name: bootloaderconfig.h
 * Project: USBaspLoader
 * Author: Christian Starkjohann
 * Author: Stephan Baerwolf
 * Creation Date: 2007-12-08
 * Modification Date: 2013-03-31
 * Tabsize: 4
 * Copyright: (c) 2007 by OBJECTIVE DEVELOPMENT Software GmbH
 * License: GNU GPL v2 (see License.txt)
 */

#ifndef __bootloaderconfig_h_included__
#define __bootloaderconfig_h_included__
#include "../misc/iofixes.h"

/*
General Description:
This file (together with some settings in Makefile) configures the boot loader
according to the hardware.

This file contains (besides the hardware configuration normally found in
usbconfig.h) two functions or macros: bootLoaderInit() and
bootLoaderCondition(). Whether you implement them as macros or as static
inline functions is up to you, decide based on code size and convenience.

bootLoaderInit() is called as one of the first actions after reset. It should
be a minimum initialization of the hardware so that the boot loader condition
can be read. This will usually consist of activating a pull-up resistor for an
external jumper which selects boot loader mode.

bootLoaderCondition() is called immediately after initialization and in each
main loop iteration. If it returns TRUE, the boot loader will be active. If it
returns FALSE, the boot loader jumps to address 0 (the loaded application)
immediately.

For compatibility with Thomas Fischl's avrusbboot, we also support the macro
names BOOTLOADER_INIT and BOOTLOADER_CONDITION for this functionality. If
these macros are defined, the boot loader usees them.
*/

/* ---------------------------- Macro Magic ---------------------------- */
#define		PIN_CONCAT(a,b)			a ## b
#define		PIN_CONCAT3(a,b,c)		a ## b ## c

#define		PIN_PORT(a)			PIN_CONCAT(PORT, a)
#define		PIN_PIN(a)			PIN_CONCAT(PIN, a)
#define		PIN_DDR(a)			PIN_CONCAT(DDR, a)

#define		PIN(a, b)			PIN_CONCAT3(P, a, b)

/* ---------------------------- Hardware Config ---------------------------- */

#ifndef USB_CFG_IOPORTNAME
  #define USB_CFG_IOPORTNAME      D
#endif
/* This is the port where the USB bus is connected. When you configure it to
 * "B", the registers PORTB, PINB and DDRB will be used.
 */
#ifndef USB_CFG_INTPORT_BIT
  #if (defined(__AVR_ATmega640__) || defined (__AVR_ATmega128__) || defined(__AVR_ATmega1280__) || defined(__AVR_ATmega1281__) || defined(__AVR_ATmega2560__) || defined(__AVR_ATmega2561__))
    #define USB_CFG_INTPORT_BIT 0
  #else
    #define USB_CFG_INTPORT_BIT 2
  #endif
#endif
/* Not all devices have their INT0 on PD2.
 * Since "INT0" and "USB_CFG_DPLUS_BIT" should get the same signals,
 * map them to be ideally the same:
 * So abstract "USB_CFG_DPLUS_BIT" to this one here.
 */

#ifndef USB_CFG_DMINUS_BIT
  /* This is Revision 3 and later (where PD6 and PD7 were swapped */
  #define USB_CFG_DMINUS_BIT      3    /* Rev.2 and previous was 6 */
#endif
/* This is the bit number in USB_CFG_IOPORT where the USB D- line is connected.
 * This may be any bit in the port.
 */
#ifndef USB_CFG_DPLUS_BIT
  #define USB_CFG_DPLUS_BIT       USB_CFG_INTPORT_BIT
#endif
/* This is the bit number in USB_CFG_IOPORT where the USB D+ line is connected.
 * This may be any bit in the port. Please note that D+ must also be connected
 * to interrupt pin INT0!
 */
#ifndef JUMPER_PORT
  #define JUMPER_PORT		USB_CFG_IOPORTNAME
#endif
/* 
 * jumper is connected to this port
 */
#ifndef JUMPER_BIT
  /* This is Revision 3 and later (where PD6 and PD7 were swapped */
  #define JUMPER_BIT           5       /* Rev.2 and previous was 7 */
#endif
/* 
 * jumper is connected to this bit in port "JUMPER_PORT", active low
 */

#define USB_CFG_CLOCK_KHZ       (F_CPU/1000)
/* Clock rate of the AVR in MHz. Legal values are 12000, 16000 or 16500.
 * The 16.5 MHz version of the code requires no crystal, it tolerates +/- 1%
 * deviation from the nominal frequency. All other rates require a precision
 * of 2000 ppm and thus a crystal!
 * Default if not specified: 12 MHz
 */

/* ----------------------- Optional Hardware Config ------------------------ */

/* #define USB_CFG_PULLUP_IOPORTNAME   D */
/* If you connect the 1.5k pullup resistor from D- to a port pin instead of
 * V+, you can connect and disconnect the device from firmware by calling
 * the macros usbDeviceConnect() and usbDeviceDisconnect() (see usbdrv.h).
 * This constant defines the port on which the pullup resistor is connected.
 */
/* #define USB_CFG_PULLUP_BIT          4 */
/* This constant defines the bit number in USB_CFG_PULLUP_IOPORT (defined
 * above) where the 1.5k pullup resistor is connected. See description
 * above for details.
 */

/* ------------------------------------------------------------------------- */
/* ---------------------- feature / code size options ---------------------- */
/* ------------------------------------------------------------------------- */
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

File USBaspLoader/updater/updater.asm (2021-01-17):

updater.elf:     file format elf32-avr

SYMBOL TABLE:
00800100 l    d  .data	00000000 .data
00000000 l    d  .text	00000000 .text
00000000 l    d  .comment	00000000 .comment
00000000 l    d  .note.gnu.avr.deviceinfo	00000000 .note.gnu.avr.deviceinfo
00000000 l    d  .debug_aranges	00000000 .debug_aranges
00000000 l    d  .debug_info	00000000 .debug_info
00000000 l    d  .debug_abbrev	00000000 .debug_abbrev
00000000 l    d  .debug_line	00000000 .debug_line
00000000 l    d  .debug_frame	00000000 .debug_frame
00000000 l    d  .debug_str	00000000 .debug_str
00000000 l    d  .debug_loc	00000000 .debug_loc
00000000 l    d  .debug_ranges	00000000 .debug_ranges
00000000 l    d  .debug_macro	00000000 .debug_macro
00000000 l    df *ABS*	00000000 updater.c
0000003e l       *ABS*	00000000 __SP_H__
0000003d l       *ABS*	00000000 __SP_L__
0000003f l       *ABS*	00000000 __SREG__
00000000 l       *ABS*	00000000 __tmp_reg__
00000001 l       *ABS*	00000000 __zero_reg__
000000b0 l       .text	00000000 loop20
000000de l       .text	00000000 loop48
00000000 l    df *ABS*	00000000 _exit.o
00000c62 l       .text	00000000 __stop_program
0000008e  w      .text	00000000 __vector_22
0000008e  w      .text	00000000 __vector_1
00800100 g     O .data	00000002 new_firmware
0000ffa0 g       *ABS*	00000000 __DATA_REGION_LENGTH__
00000090 g     F .text	0000002e do_spm
00000aa2 g     F .text	00000012 memcpy_PF
00000068 g       .text	00000000 __trampolines_start
00000c64 g       .text	00000000 _etext
0000008e  w      .text	00000000 __vector_24
0000008e  w      .text	00000000 __vector_12
0000008e g       .text	00000000 __bad_interrupt
00000218 g       .text	00000000 usbasploader
00000c66 g       *ABS*	00000000 __data_load_end
0000008e  w      .text	00000000 __vector_6
00000068 g       .text	00000000 __trampolines_end
0000008e  w      .text	00000000 __vector_3
0000008e  w      .text	00000000 __vector_23
00000c64 g       *ABS*	00000000 __data_load_start
00000068 g       .text	00000000 __dtors_end
00000400 g       *ABS*	00000000 __LOCK_REGION_LENGTH__
0000008e  w      .text	00000000 __vector_25
0000008e  w      .text	00000000 __vector_11
00000068  w      .text	00000000 __init
00000aa2 g       .text	00000000 _binary_usbasploader_raw_end
0000008e  w      .text	00000000 __vector_13
0000008e  w      .text	00000000 __vector_17
0000008e  w      .text	00000000 __vector_19
0000008e  w      .text	00000000 __vector_7
00810000 g       .text	00000000 __eeprom_end
00000000 g       .text	00000000 __vectors
00800102 g       .data	00000000 __data_end
0000088a g       *ABS*	00000000 _binary_usbasploader_raw_size
00000000  w      .text	00000000 __vector_default
0000008e  w      .text	00000000 __vector_5
00000112 g     F .text	00000106 mypgm_WRITEpage
000000ec g     F .text	00000026 mypgm_readpage
00000400 g       *ABS*	00000000 __SIGNATURE_REGION_LENGTH__
00000068 g       .text	00000000 __ctors_start
00000074 g       .text	00000016 .hidden __do_copy_data
00000c52 g     F .text	0000000e memset
00000ab4 g     F .text	0000019e main
0000008e  w      .text	00000000 __vector_4
00000000  w      *ABS*	00000000 __heap_end
0000008e  w      .text	00000000 __vector_9
0000008e  w      .text	00000000 __vector_2
00000400 g       *ABS*	00000000 __USER_SIGNATURE_REGION_LENGTH__
0000008e  w      .text	00000000 __vector_21
0000008e  w      .text	00000000 __vector_15
00000068 g       .text	00000000 __dtors_start
00000068 g       .text	00000000 __ctors_end
000008ff  w      *ABS*	00000000 __stack
00800102 g       .data	00000000 _edata
00800102 g       .text	00000000 _end
0000008e  w      .text	00000000 __vector_8
00000c60  w      .text	00000000 .hidden exit
00010000 g       *ABS*	00000000 __EEPROM_REGION_LENGTH__
00000c60 g       .text	00000000 .hidden _exit
0000008e  w      .text	00000000 __vector_14
000000be g     F .text	0000002e temp_do_spm
0000008e  w      .text	00000000 __vector_10
0000008e  w      .text	00000000 __vector_16
00800100 g       .data	00000000 __data_start
0000008e  w      .text	00000000 __vector_18
00000400 g       *ABS*	00000000 __FUSE_REGION_LENGTH__
00020000 g       *ABS*	00000000 __TEXT_REGION_LENGTH__
0000008e  w      .text	00000000 __vector_20



Disassembly of section .text:
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

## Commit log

2021-01-17 hello world
    [bom.csv, framework-acrylic-base.dxf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]
2021-01-17 Added .pdf schematic for rev. 1 + readme tweaks
    [framework.sch]
2021-01-20 add more images
    [framework-acrylic-grid.kicad_pcb]
2021-01-25 Fix mixed up MOSI and MISO connections for ISP
    [framework.kicad_pcb, framework.sch]
2021-01-26 add acrylic cover + update schematic pdf
    [framework-acrylic-base-Edge_Cuts.dxf, framework-acrylic-base.kicad_pcb, framework-acrylic-grid-Edge_Cuts.dxf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]
2021-01-26 update gerbers
    [framework-B_Cu.gbl, framework-B_Mask.gbs, framework-B_SilkS.gbo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]
2021-01-26 Dimension acrylic
    [framework-acrylic-base.kicad_pcb, framework-acrylic-grid.kicad_pcb, framework-acrylic-shield.kicad_pcb]
2021-02-07 board aesthetic changes
    [framework.kicad_pcb]
2021-02-28 Documentation changes
    [framework-acrylic-base.dxf, framework-acrylic-grid.dxf, framework-acrylic-shield.dxf]
2021-03-03 move fish logo slightly
    [framework-B_Cu.gbl, framework-B_Mask.gbs, framework-B_SilkS.gbo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]
2021-08-12 correct schematic: schottky to zener diode symbols on USB d+/d-
    [framework.sch]
2021-08-12 changed schematic, schottky to zener diode symbol on USB d+/d-
2021-08-23 clean up acrylic shield .kicad-pcb file + add .step export
    [framework-acrylic-shield.kicad_pcb, framework-acrylic-shield.step]
2021-08-23 fix mounting hole misalignment on backplate
    [framework-B_Cu.gbl, framework-B_Mask.gbs, framework-B_SilkS.gbo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]
2021-08-23 fix .step export for misaligned backplate hole
2021-09-11 file rename + cleanup
    [framework-acrylic-base.dxf, framework-acrylic-base.kicad_pcb, framework-acrylic-base.step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]
2021-09-28 Add standard component name for Bill of Materials
    Added standard component names for Bill of Materials for easier reference and lookup.
2021-11-30 fix framework.h link
2021-12-08 add usb c soldering video reference
2022-03-19 add files for 3d printing and manufacturing sandwich case layers
    [bottom.step, bottom.stl, top.step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]
2022-07-09 rename directory rev1/acrylic -> rev1/dxf_layers; update rev1/3d_layers/bottom.* to include mounting points for acrylic shield
    [bottom.step, bottom.stl, framework-acrylic-lower.dxf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]
